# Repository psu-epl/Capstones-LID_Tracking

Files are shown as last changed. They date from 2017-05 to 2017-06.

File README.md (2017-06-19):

Capstones-LID_Tracking
------

###### This is the top level directory for the Capstone Awesome Usage Monitor project. The following repo directories contain the files used by this project and the developers to specify, design, and implement the project. This directory may be copied whole into any preconfigured Django AUM project instance. See below on how to configure and setup an AUM project instance.

---

* ./sm/ - Files associated with the Station Module. Not used by Django.
* ./aum/ - Django associated python files for the aum project and used by all applications.
* ./aumwi/ - Django associated python files for the web interface application.
* ./doc/ - Project Documentation, including User Manuals.
* ./static/ - css, js, img, and font files used by Django to render webpages, organized by project
* ./templates/registration/ - Django authentication and password management html files
* ./testing/ - Testing software and associated coverage results zip
* ./manage.py - Django management code.

---

The development environment for the Awesome Usage Monitor used an Ubuntu 16.04 server instance with python3.0 installed and running as a virtual environment.  The server was configured with SMTP, a postgreSQL database, Gunicorn application server, and Nginx setup as the webserver and the reverse proxy to Gunicorn.  Django 1.11 was used to develop the project.

---

The test environment was created using pytest and pytest-django for python3, for detailed instructions on how to create additional tests or verify the functionality of your production instance of the Awesome Usage Monitor please visit this [Pytest-Django Tutorial](http://pytest-django.readthedocs.io/en/latest/tutorial.html)

---

For detailed instructions on how to create a production environment similar to the development environment please visit this [DigitalOcean Tutorial](https://www.digitalocean.com/community/tutorials/how-to-set-up-django-with-postgres-nginx-and-gunicorn-on-ubuntu-16-04).

---

For detailed documentation on any Django function used within the project, please refer to the [Django 1.11 Documentation](https://docs.djangoproject.com/en/1.11/) or the [Django source code](https://github.com/django/django), both of which are extensive and extremely helpful.

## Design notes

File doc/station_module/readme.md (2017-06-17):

## Station Module

[How to set up the module](Setup.md) (connect to the Wifi, set parameters, etc)

[Using the Module](use.md)

[Brief description of Hardware and pin assignments](pin.md)

[Bill of Materials](bom.md)

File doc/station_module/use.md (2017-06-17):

### Using the Station Module:

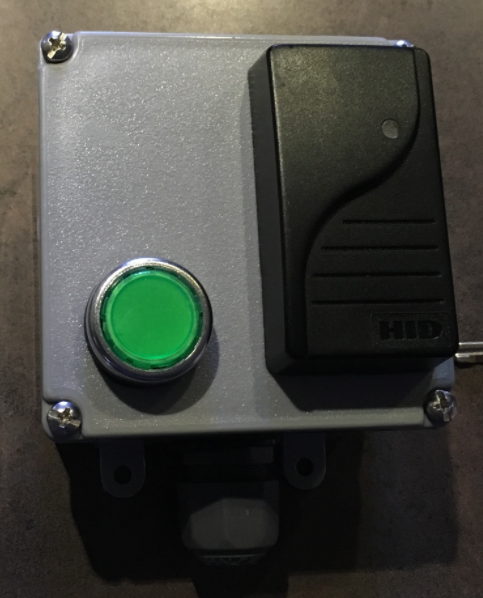
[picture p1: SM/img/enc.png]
Station Module in Enclosure


#### Normal Login
When a registered user swipes a card, the SM sends a request to the database, if the user is authorized, the SM light a green LED and send power to the external relay. The database logs the entry with a timestamp. It can take up to 4 seconds to recieve a reply from the server.
If the user is unauthorized, the SM will emit a beep and remain off.
If it takes 15s or more to get a reply, this indicates that the SM is timing out with the server. Debugging info is available on the serial port of the SM.

#### Logout
Pushing the attached button causes the relay to be shut off and a logout command to be sent to the database. A logout timestamp is added to the last login entry.

#### Double Scanning
If a user is logged in, and another user badges in on top of them, the module will stay logged in under the new user.
If an unauthorized user tries to login over an existing session, the SM will end the session.

#### Add user
For a manager to add a user, they will hold down the button and scan their badge. The SM will blink alternating red and green for 10 seconds. The new user will scan their badge and the info is sent to the database.  If the add is successful, the SM will log in.

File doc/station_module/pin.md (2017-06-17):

#### ESP8266 - 12E 
<a href="https://espressif.com/en/products/hardware/esp8266ex/overview">EXPRESSIF</a>

This module was chosen for it's cost/size/power consumption, and prior experience the team had using them.<br>
Also the following:
- Features:
  - 802.11 b/g/n
  - Integrated TCP/IP protocol stack
  - 32-bit MCU running at 80MHz
  - 4M Flash memory
  - Integrated 10-bit ADC
  - SDIO 2.0, (H) SPI, UART, I2C, I2S, IRDA, PWM, GPIO

#### ESP Pin Functions:
| Pin | Function |
|---|---|
| GPIO 0  | Green LED status indicator |
| GPIO 1  | SPI Slave Select 1 |
| GPIO2 | Audible alarm control |
| GPIO 3  | SPI Slave Select 2 |
| GPIO 4  | RFID-DATA1 |
|  GPIO 5 | RFID-DATA0 |
| GPIO 12 | SPI MOSI |
| GPIO 13 | SPI MISO |
| GPIO 14 | SPI Clock |
| GPIO 15 | APD Enable |
| ADC | Stop / Logout |

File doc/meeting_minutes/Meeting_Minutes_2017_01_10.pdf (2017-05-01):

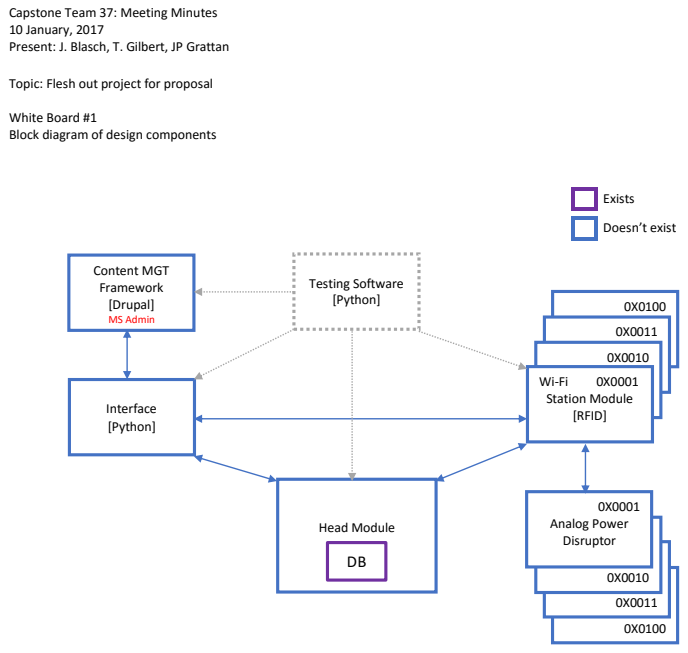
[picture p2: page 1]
Content MGT Framework [Drupal] MS Admin; Interface [Python]; Head Module; Station Module [RFID]; Testing Software [Python]; 0X0001 Analog Power Disruptor; Exists; Doesn’t exist

Capstone Team 37: Meeting Minutes
10 January, 2017
Present: J. Blasch, T. Gilbert, JP Grattan

Topic: Flesh out project for proposal

White Board #1
Block diagram of design components

0X0011
0X0010

10 January, 2017
Present: J. Blasch, T. Gilbert, JP Grattan

Whiteboard #2
Block diagram of interface setup

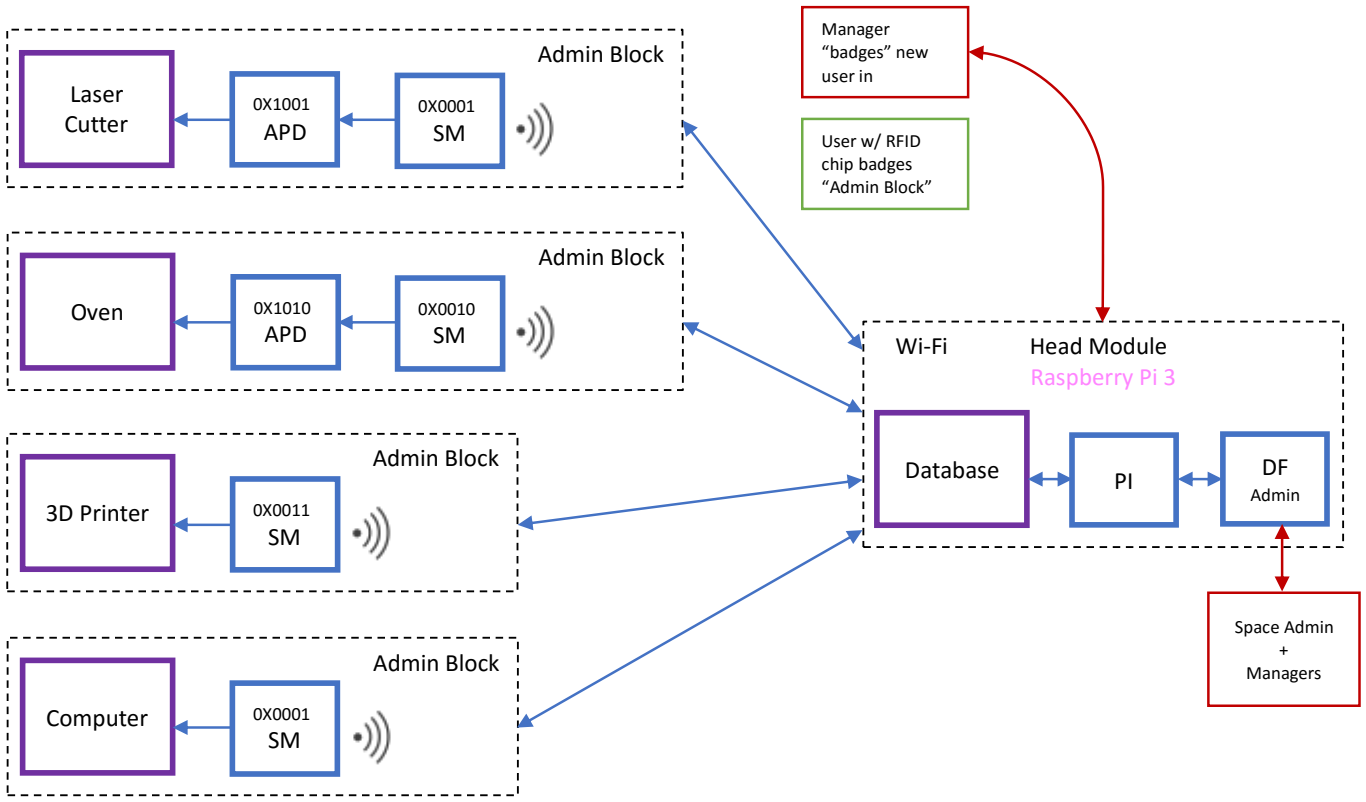
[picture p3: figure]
Admin Block; Laser Cutter; 0X1001 APD; Oven; APD; 3D Printer; Computer; Head Module; Raspberry Pi 3; Database; Admin PI; Space Admin + Managers; Manager “badges” new user in; User w/ RFID chip badges “Admin Block”

10 January, 2017
Present: J. Blasch, T. Gilbert, JP Grattan

Whiteboard #3
Design Questions

SM = Station Module

How does a new user get added to the “list”?

- Manager badges twice within 1 second and within x-seconds the user badges. | Individual
- Manager badges and, while the manager pushes a button, the user badges. | – MIX
- Manager accesses Drupal frontend and manually adds user. | Batch & individual

What does a “pass” event look like?

User puts RFID card to SM. SM communicates wirelessly with database and receives “pass”. SM sends signal to APD to turn on and credentials to log in to computer.

What does a “fail” event look like?

User puts RFID card to SM. SM communicates wirelessly with database and receives “fail”. SM alerts with audio and visual signal.

How does the SM pass credentials?

This is uncertain and subject to further investigation. It is physically attached to the computer, so perhaps USB.

How does the SM communicate with the APD?

This is uncertain and subject to further investigation. It is physically attached to the APD, so perhaps I²C.

Perhaps audio and visual “pass” signal for manager?

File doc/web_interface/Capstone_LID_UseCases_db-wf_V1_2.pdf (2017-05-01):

### CAPSTONE – LID: Use Cases db/web framework

Version 1.2

Team: Jessica Blasch, Tyson Gieszler, Tyler Gilbert, JP Grattan

Version History
Version # | Revision Date | Responsible Party | Reason
1.0 | 27 February, 2017 | Jessica Blasch | Initial compilation of source document
1.1 | 04 March, 2017 | Jessica Blasch | Revision to create simpler use cases
1.2 | 015 March, 2017 | Jessica Blasch | Revision add use cases for reports ‘Prev’/’Next’ BTN

## Table of Contents

## Access the System: Logging In

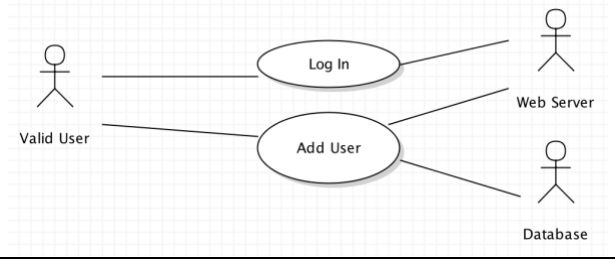
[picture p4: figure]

Use Case | Log in
Actors | Valid user, Web server, Database
Description | This use-case occurs when a valid user (owner, admin, or manager) logs in to the system. The web server will prompt the user for their log-in information. If they are not a valid user, the system will not allow them access past the log-in page. If they are a valid user, they will be directed to the ‘Add User’ page view. The ability to make a new user an owner, admin, or manager will be made available depending on the user’s status. (e.g. If owner, display options for make owner, admin, or manager. If admin only display ‘make manager’ . If manager, do not display options to make owner, admin, or manager.)
Stimulus | User logs in to system.
Response | Verify user is a valid user and their status. If valid, trigger appropriate ‘Add User’ page view with respect to the user’s credentials

## Exit the System: Logging Out

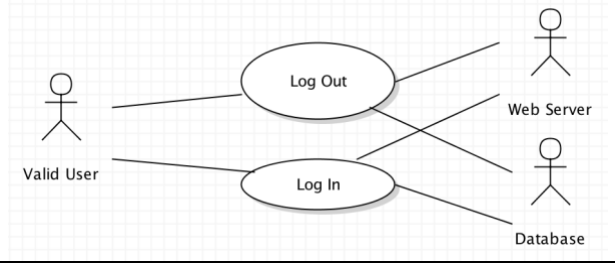
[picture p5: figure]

Use Case | Log Out
Actors | Valid user, Web server, Database
Description | This use-case occurs when a valid user (owner, admin, or manager) is in the system and wants to log out. When the user selects the ‘Log Out’ button, the web server will redirect to the ‘Log In’ page view.
Stimulus | User selects ‘Log Out’ button.
Response | Trigger ‘Log In’ page view.

## Add a New User

### Navigating to the ‘Add User’ Page

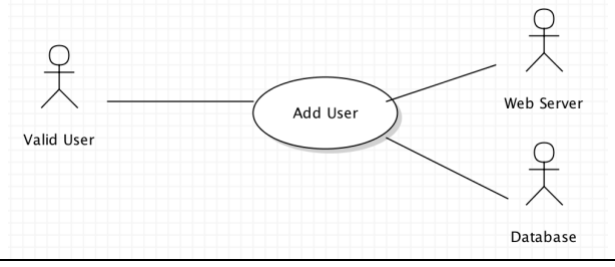
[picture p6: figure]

Use Case | Display ‘Add User’ Page View
Actors | Valid user, Web server, Database
Description | This use-case occurs when a valid user (manager, admin, or owner) must navigate to the ‘Add User’ page view from another page view by selecting the ‘Add User’ button. Upon selecting the ‘Add User’ button, the web server will redirect to the ‘Add User’ page view.
Stimulus | User selects ‘Add User’ button.
Response | Trigger ‘Add User’ page view.

### Saving a New User Entry

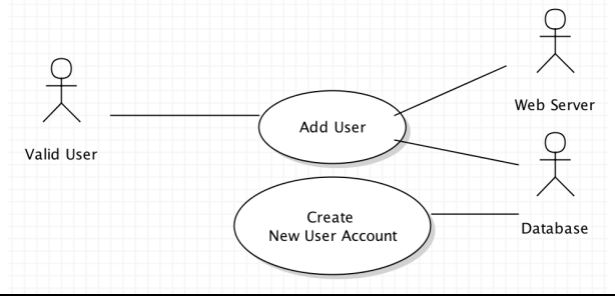
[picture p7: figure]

Use Case | Save New User Entry
Actors | Valid user, Web server, Database
Description | This use-case occurs when a valid user (manager, admin, or owner) is at the ‘Add User’ page view. The user may then fill in information in editable fields for a new user account and save it as a new entry in the database.
Stimulus | User selects ‘Save’ button.
Response | Verify all fields are correctly filled out. Save as new user account entry in database.

## Search for a User

### Navigating to the ‘Find User’ Page

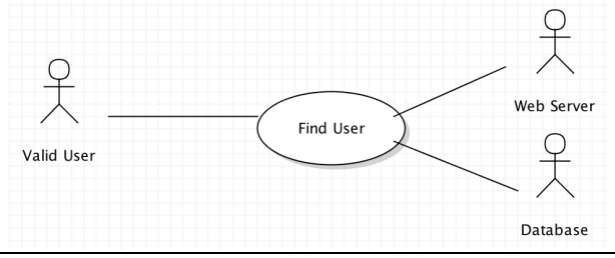
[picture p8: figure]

Use Case | Display ‘Find User’ Page
Actors | Valid user, Web server, Database
Description | This use-case occurs when a valid user (manager, admin, or owner) navigates to the ‘Find User’ page view by selecting the ‘Find User’ button.
Stimulus | User selects ‘Find User’ button.
Response | Trigger ‘Find User’ page view.

Searching for a User with Name –AND– I.D.

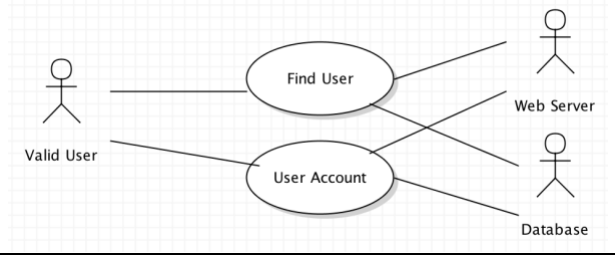
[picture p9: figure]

Use Case | Search User Account with Name –AND– I.D.
Actors | Valid user, Web server, Database
Description | This use-case occurs when a valid user (manager, admin, or owner) is at the ‘Find User’ page view. If the user enters the name and badge I.D. that matches an entry in the database, when they select the ‘search’ button, they will be directed to the specific account page for that user.
Stimulus | User selects ‘Search’ button.
Response | Verify all fields match a database entry. If valid, trigger ‘User Account’ page view.

Searching for a User with Name –OR– I.D.

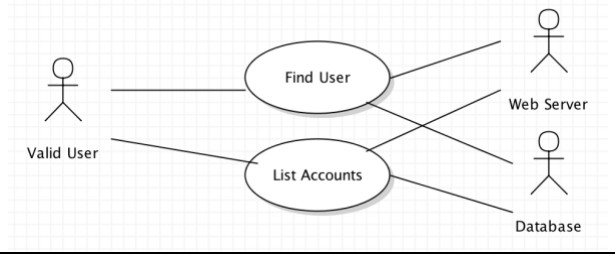
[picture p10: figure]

Use Case | Search User Account with Name –OR– I.D.
Actors | Valid user, Web server, Database
Description | This use-case occurs when a valid user (manager, admin, or owner) is at the ‘Find User’ page view. If the user does not enter all fields (name and badge I.D.) or does not enter a name and badge I.D. that matches an entry in the database, when they select the ‘search’ button, they will be directed to a list of users and badge I.D.s with fields that match any of the fields searched for. The user may then write down the information they need and search again using the ‘Find User’ button.
Stimulus | User selects ‘Search’ button.
Response | Verify all fields match a database entry. If not valid, trigger ‘List Accounts’ page view of user accounts with fields that match search criteria.

## Edit a User Account

### Navigating to an Editable User Account

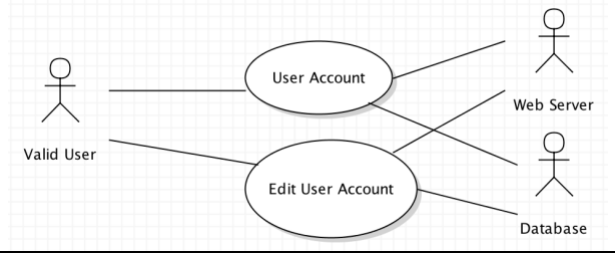
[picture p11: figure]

Use Case | View Editable User Account
Actors | Valid user, Web server, Database
Description | This use-case occurs when a valid user (manager, admin, or owner) is at a specific ‘User Account’ page view. If the user selects the ‘Edit’ button, they will be redirected to an ‘Edit User Account’ page view with editable fields for the user searched.
Stimulus | User selects ‘Edit’ button.
Response | Trigger ‘Edit User Account’ page view.

### Saving User Account Edits

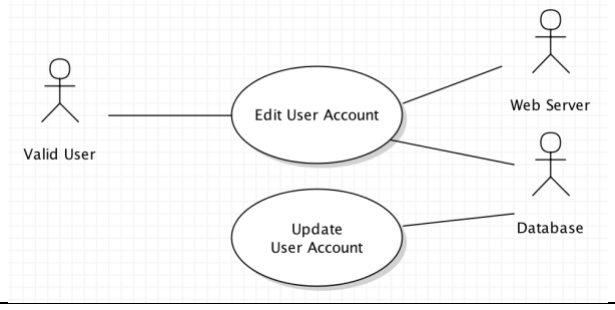
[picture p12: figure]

Use Case | Save User Account Edits
Actors | Valid user, Web server, Database
Description | This use-case occurs when a valid user (manager, admin, or owner) is at the ‘Edit User Account’ page view. From this page, the user can edit fields of a user account including status as an owner, admin or manager if they have appropriate credentials. (e.g. If owner, display options for make owner, admin, or manager. If admin only display ‘make manager’ . If manager, do not display options to make owner, admin, or manager.)
Stimulus | User selects ‘Save’ button.
Response | Verify all fields are correctly filled out. Save edits for account entry in database.

## Delete a User Account

### Navigating to Delete User Account

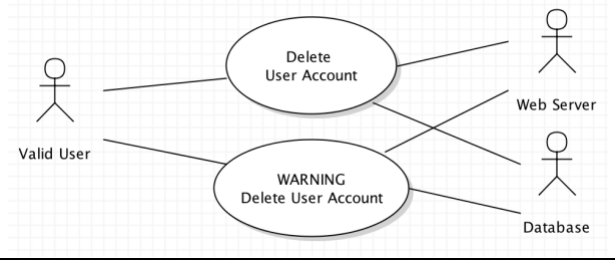
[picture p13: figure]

Use Case | Begin Delete User Account
Actors | Valid user, Web server, Database
Description | This use-case occurs when a valid user (manager, admin, or owner) is at a specific ‘User Account’ page view. If the user selects the ‘Delete’ button, they will be redirected to a ‘Warning’ page view to confirm or cancel deletion.
Stimulus | User selects ‘Delete’ button.
Response | Trigger ‘Warning’ page view.

### Canceling User Account Deletion

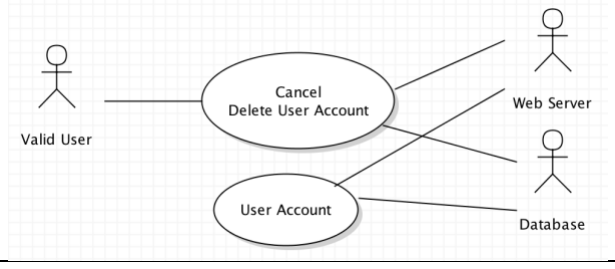
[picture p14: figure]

Use Case | Cancel Delete User Account
Actors | Valid user, Web server, Database
Description | This use-case occurs when a valid user (manager, admin, or owner) is at the ‘Warning’ page view, before account deletion. If the user selects the ‘Cancel’ button, they will be redirected back to the specific ‘User Account’ page view.
Stimulus | User selects ‘Cancel’ button.
Response | Trigger ‘User Account’ page view.

### Confirming User Account Deletion

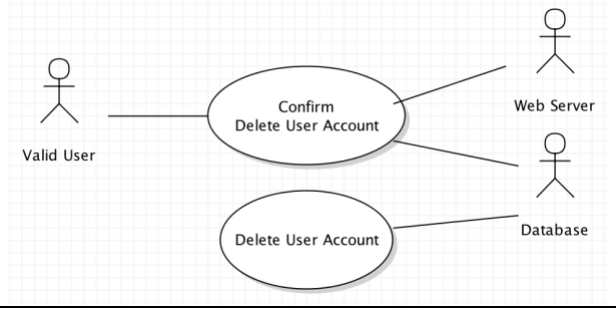
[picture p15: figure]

Use Case | Confirm Delete User Account
Actors | Valid user, Web server, Database
Description | This use-case occurs when a valid user (manager, admin, or owner) is at the ‘Warning’ page view, before account deletion. If the user selects the ‘Confirm’ button, the entry will be removed from the database and the user will be redirected to a ‘Delete Confirmation’ page view which will confirm the deletion has occurred.
Stimulus | User selects ‘Confirm’ button.
Response | Delete user account entry in the database. Trigger ‘Delete Confirmation’ page view.

## Search for a Station

### Navigating to the ‘Find Station’ Page

Use Case | Display ‘Find Station’ Page
Actors | Valid user, Web server, Database
Description | This use-case occurs when a valid user (manager, admin, or owner) navigates to the ‘Find Station’ page view by selecting the ‘Find Station’ button.
Stimulus | User selects ‘Find Station’ button.
Response | Trigger ‘Find Station’ page view.

### Searching for a Station

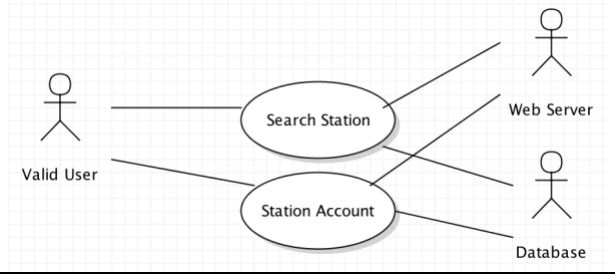
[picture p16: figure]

Use Case | Search for a Station
Actors | Valid user, Web server, Database
Description | This use-case occurs when a valid user (manager, admin, or owner) is at the ‘Find Station’ page view. At this page view, the user can enter in the I.D. of the station they wish to look up. After selecting the ‘search’ button, the web server will verify the I.D. matches an entry in the database and redirect the user to a page view of the station’s information.
Stimulus | User selects ‘Search’ button.
Response | Verify I.D. matches a database entry. Trigger ‘Station Account’ view.

## Edit a Station

### Navigating to an Editable Station View

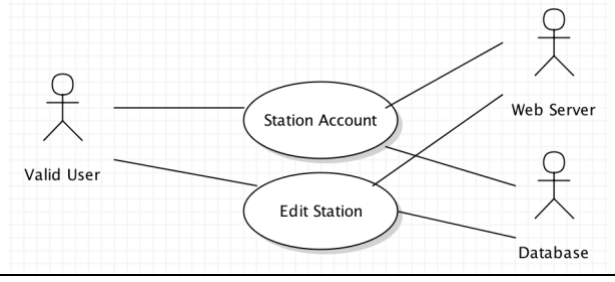
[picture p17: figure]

Use Case | Go to Editable Station View
Actors | Valid user, Web server, Database
Description | This use-case occurs when a valid user (manager, admin, or owner) is at a station account page view. After selecting the ‘edit’ button, the web server will redirect them to an editable page view of the station’s information.
Stimulus | User selects ‘Edit’ button.
Response | Trigger ‘Edit Station’ page view.

### Saving Station Edits

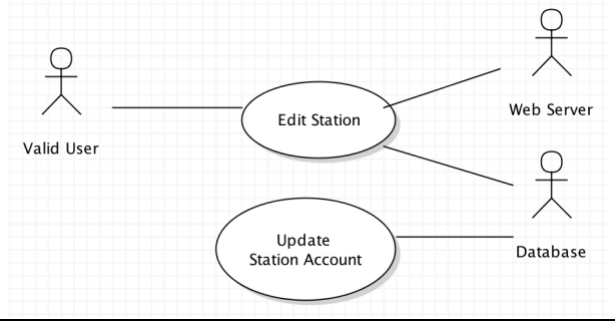
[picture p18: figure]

Use Case | Save Station Edits
Actors | Valid user, Web server, Database
Description | This use-case occurs when a valid user (manager, admin, or owner) is at the editable station account page view. After selecting the ‘save’ button, the information will be updated and stored in the database.
Stimulus | User selects ‘Save’ button.
Response | Update station account in database.

## Delete a Station

### Removing a Station

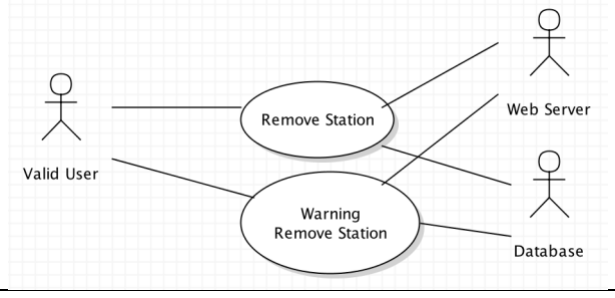
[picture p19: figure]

Use Case | Remove a Station
Actors | Valid user, Web server, Database
Description | This use-case occurs when a valid user (manager, admin, or owner) is at a station account page view. If the user selects the ‘Remove Station’ button, they will be redirected to a ‘Warning’ page view where they can cancel or confirm the data entry deletion.
Stimulus | User selects ‘Remove Station’ button.
Response | Trigger ‘Warning’ page view.

### Cancelling Station Deletion

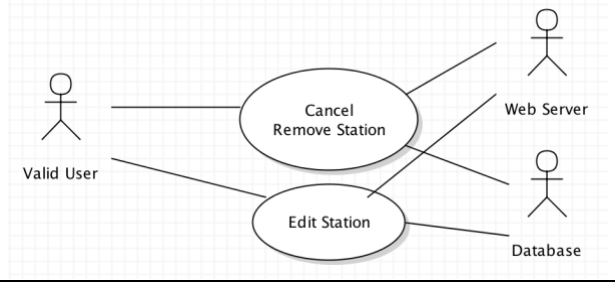
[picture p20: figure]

Use Case | Cancel Station Removal
Actors | Valid user, Web server, Database
Description | This use-case occurs when a valid user (manager, admin, or owner) is at the ‘Warning’ page view for station removal. If the user selects the ‘Cancel’ button, they will be redirected to a ‘Editable Account’ page view as though they had selected ‘Edit’ from the station account page view. From there, the user may select save and continue.
Stimulus | User selects ‘Cancel’ button.
Response | Trigger ‘Edit Station’ page view.

### Confirming Station Deletion

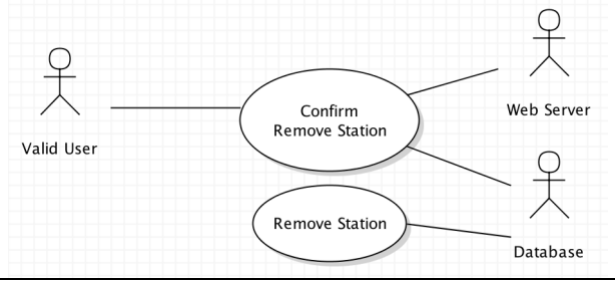
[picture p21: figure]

Use Case | Confirm Station Removal
Actors | Valid user, Web server, Database
Description | This use-case occurs when a valid user (manager, admin, or owner) is at the ‘Warning’ page view. If the user selects the ‘Confirm’ button, the station entry will be deleted from the database and the user will be redirected to a page view showing the station has been removed.
Stimulus | User selects ‘Confirm’ button.
Response | Delete station account entry in the database.

## Reports

### Running a General Report

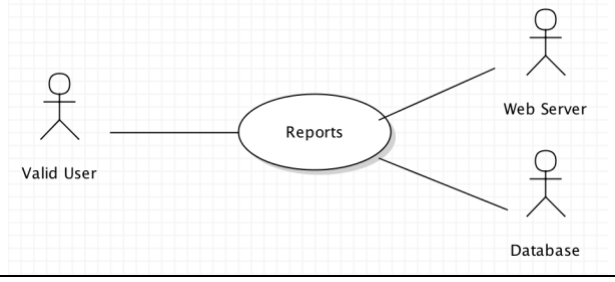
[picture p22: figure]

Use Case | Run a General Report
Actors | Valid user, Web server, Database
Description | This use-case occurs when a valid user (manager, admin, or owner) selects the ‘Reports’ button from the side table. The web server will redirect to a general ‘Report’ page view that displays all tracked data.
Stimulus | User selects ‘Reports’ button.
Response | Trigger ‘Report’ page view.

### Running a Filtered Report

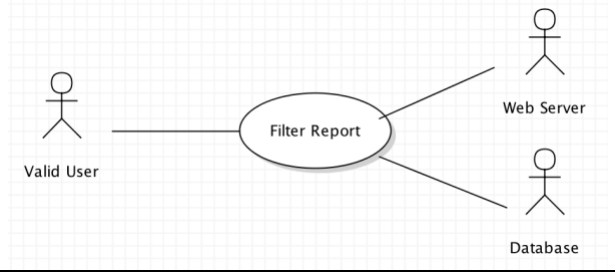
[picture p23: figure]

Use Case | Run a Filtered Report
Actors | Valid user, Web server, Database
Description | This use-case occurs when a valid user (manager, admin, or owner) is at the general ‘Report’ page view that displays all tracked data. The user may select filter options to pare down the data displayed
Stimulus | User selects ‘Filter’ button.
Response | Verify filter selections and match to database entries. Trigger ‘Filter Report’ page view.

### Navigating Reports by Page Number

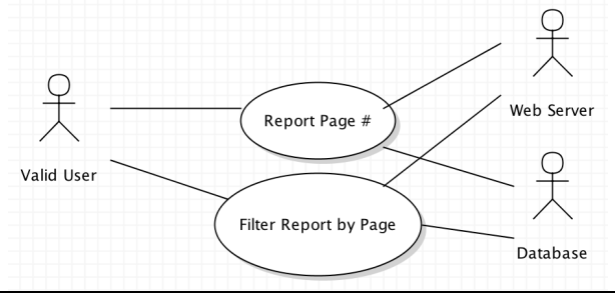
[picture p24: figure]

Use Case | Navigate Report by Page Number
Actors | Valid user, Web server, Database
Description | This use-case occurs when a valid user (manager, admin, or owner) is at the either the general ‘Report’ page view or “Filter Report’ page view. If the user selects one of the buttons for the pages of data in the report, the webserver will redirect to the page view for that part of the report data.
Stimulus | User selects ‘page number’ button.
Response | Verify the number selected. Trigger page view for that section of the report data.

### Navigating Reports with ‘Next’


Use Case | Navigate Report Pages
Actors | Valid user, Web server, Database
Description | This use-case occurs when a valid user (manager, admin, or owner) is at the either the general ‘Report’ page view or “Filter Report’ page view. If the user selects the ‘Next’ button for the pages of data in the report, the webserver will redirect to the page view for the next section of the report data.
Stimulus | User selects ‘Next’ button.
Response | Verify there is further data to display. Trigger ‘Next Page’ view.

### Navigating Reports with ‘Prev’


Use Case | Navigate Report Pages
Actors | Valid user, Web server, Database
Description | This use-case occurs when a valid user (manager, admin, or owner) is at the either the general ‘Report’ page view or “Filter Report’ page view. If the user selects the ‘Prev’ button for the pages of data in the report, the webserver will redirect to the page view for the previous section of the report data.
Stimulus | User selects ‘Prev’ button.
Response | Verify not displaying first page of data. Trigger ‘Previous Page’ view.

### Export Report as CSV File


Use Case | Export Report as CSV file
Actors | Valid user, Web server, Database
Description | This use-case occurs when a valid user (manager, admin, or owner) is at the either the general ‘Report’ page view or “Filter Report’ page view. If the user selects the ‘Export as CSV’ button, the data being displayed will be exported as a CSV file.
Stimulus | User selects ‘Export as CSV’ button.
Response | Export data as CSV file.

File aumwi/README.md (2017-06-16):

Awesome Usage Monitor Web Interface
------

* ./templates/ - Application specific html templates
* ./__init__.py - Python file to designate the directory as an importable package. May be empty or contain package initialization instructions.
* ./admin.py - Application override functions for Django model administration
* ./apps.py - Application configuration class definitions and settings
* ./forms.py - Model form definitions
* ./managers.py - Application override classes for model "managers". Django managers perform admin functions on the database models. 
* ./models.py - Application definitions for database models.
* ./test.py - Application specific testing definitions. None currently. 
* ./urls.py - Appliation specific url patterns for resolving http requests. Associates a url pattern with a function to be run by the application.
* ./views.py - Application specific class and function definitions. A "view" defines the backend rendering and processing logic for a url

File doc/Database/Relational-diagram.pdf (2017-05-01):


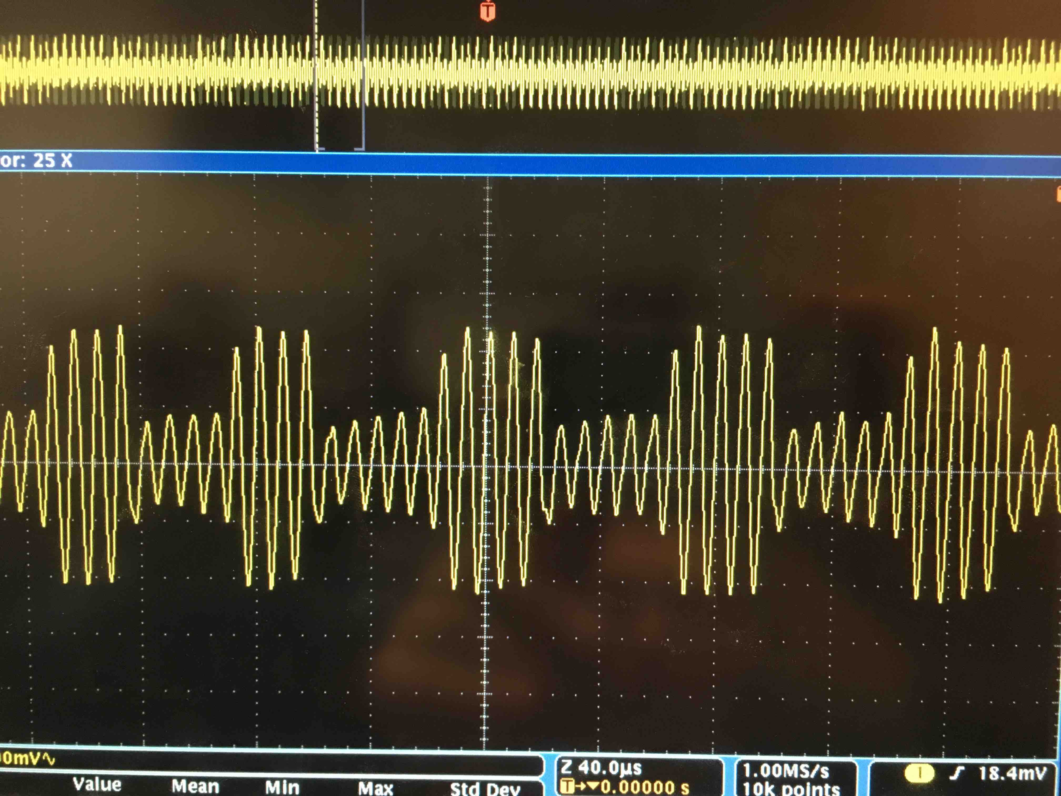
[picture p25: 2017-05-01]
doc/station_module/PSUID.jpg

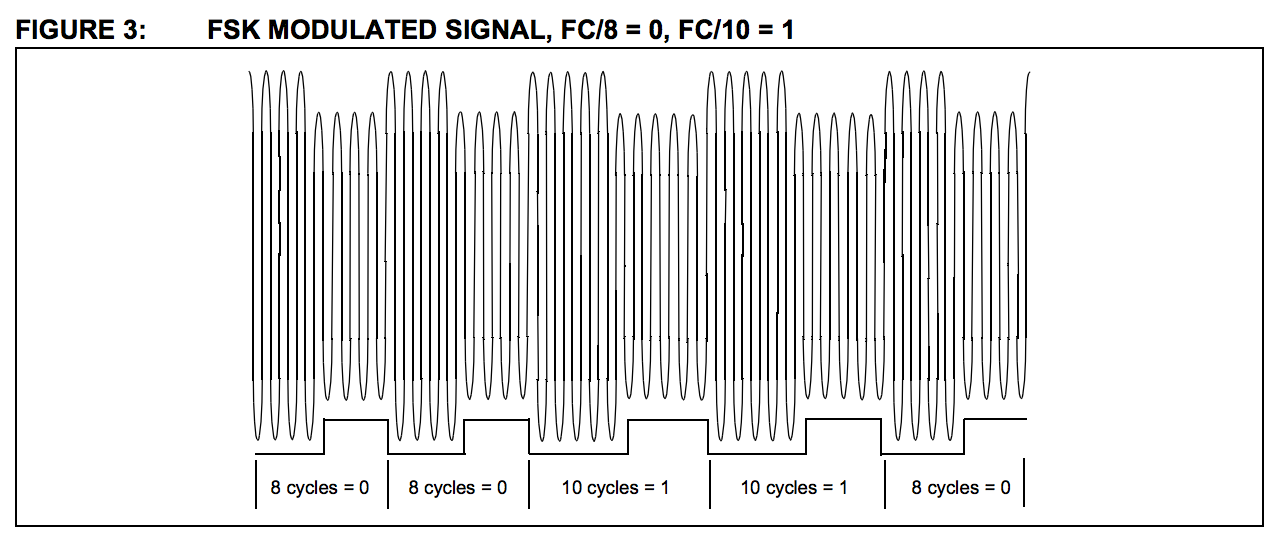
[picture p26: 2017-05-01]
doc/station_module/FSK_modulation.png

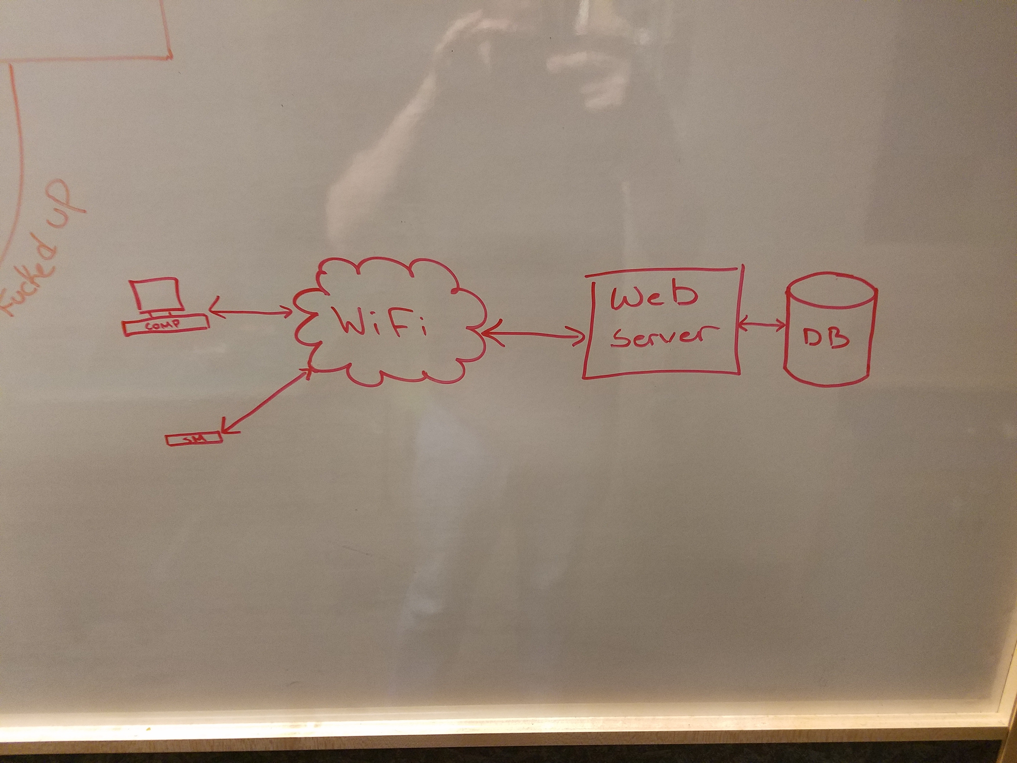
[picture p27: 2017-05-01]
doc/web_interface/Comm_Channels_prelim.jpg

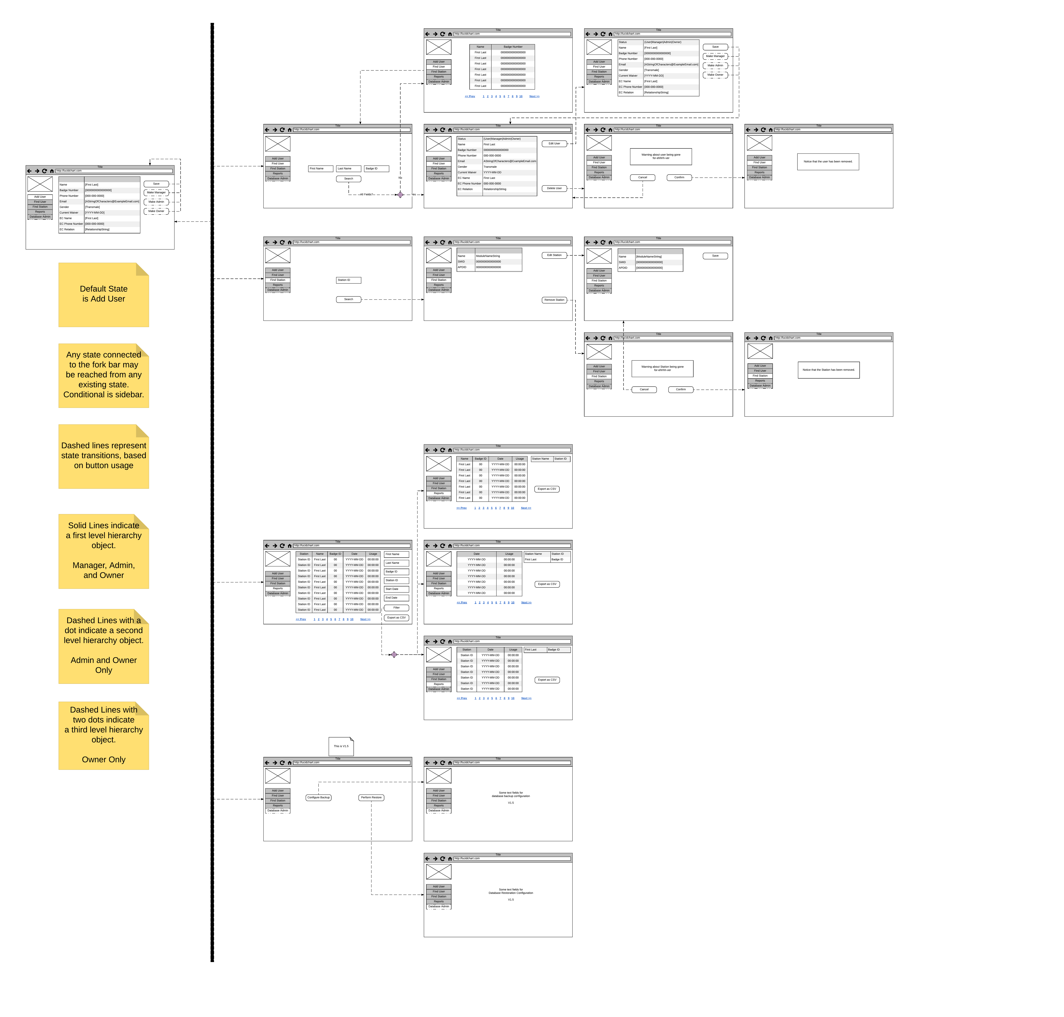
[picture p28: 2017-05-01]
doc/web_interface/Site_State_Diagram.png

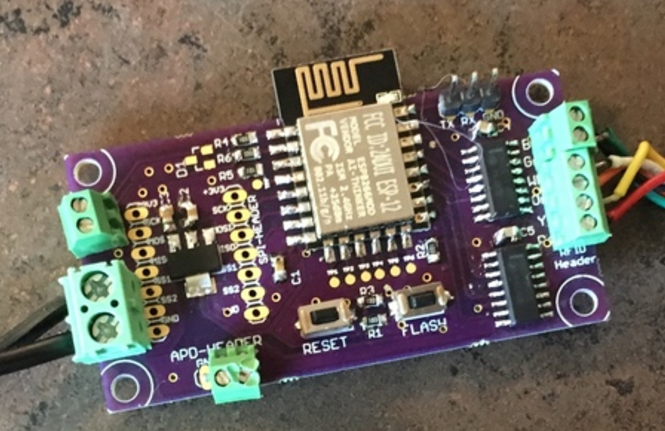
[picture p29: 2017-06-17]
doc/station_module/img/HW.png

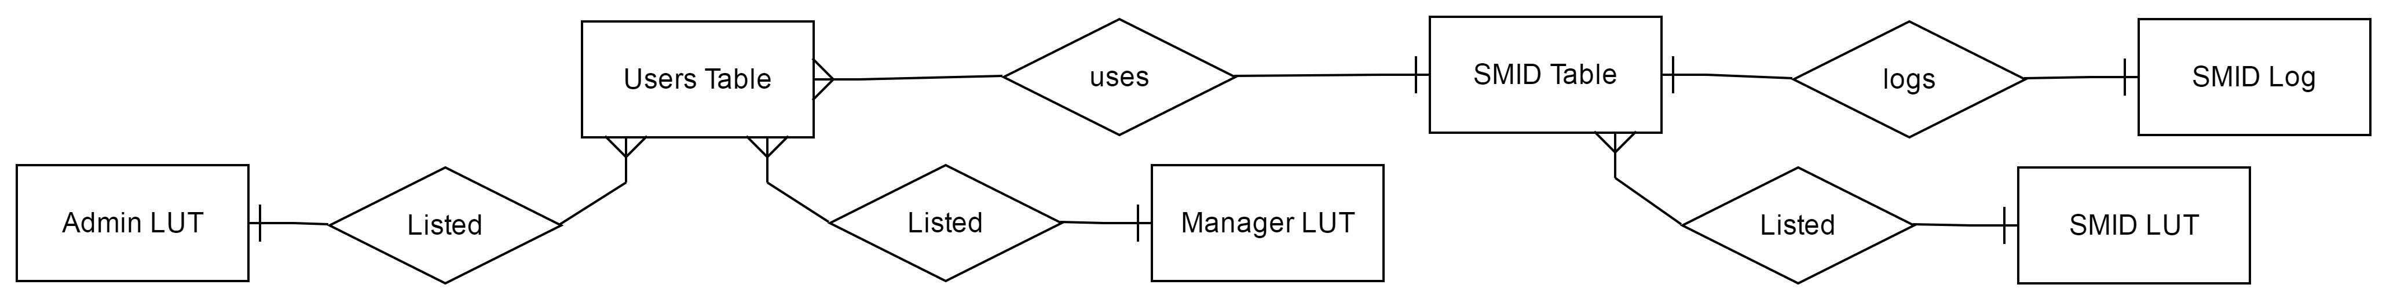
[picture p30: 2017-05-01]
doc/Database/Entity-diagram.png

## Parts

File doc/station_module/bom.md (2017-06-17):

### BOM:

The relay control output will supply a 5V signal at up to 6mA.
[Power Switch Tail 2](http://www.powerswitchtail.com/) was used successfully. It is superceded by the [IOT Relay](http://www.digital-loggers.com/iot.html), which can be found at [Adafruit](https://www.adafruit.com/product/2935)

The RFID readers that will work with this module are the [HID-PROX 125kHz readers](https://www.hidglobal.com/products/readers/hid-prox-readers)
 (HID Proxpro II, HID Proxpoint plus.. etc) that use the Wiegand protocol.

| Qty | Value | Device | Package | Parts | Description | Digikey | Mouser |
|-----|---|---|---|---|---|---|---|
| 1 | | ESP12ESMD  | ESP12E-SMD | U1 | ESP12E Module | 1528-1438-ND | 485-2491 |
| 1 | 3.3V  | D1 | SOT23 | D1 | TVS Diode | MMBZ5V6ALT1GOSCT-ND | 863-MMBZ5V6ALT1G |
| 2 | | DTSM-3 | DTSM-3 | S1,S2 | flash and reset button | 450-2146-1-ND | FSM2JMTR |
| 1 | 3.3V  | REG1117 | SOT223 | IC1 | 800mA and 1A Low Dropout (LDO) Positive Regulator  | AZ1117CH-3.3TRG1DICT-ND | 621-AZ1117CH-3.3TRG1 |
| 2 | | 4050B | 16-SOIC | U1, U2 | 6ch Buffer | MC14050BDR2GOSCT-ND | 863-MC14050BDR2G |
| 2 | 1x7 | | FEM 1x7POS .1" | SPI_Header | SPI header breakout(optional) | | |
| 1 | 1x6 | | Term block 6-pos .1" screw term | APD / RFID Header  | Screw Terminal for RFID scanner | ED10565-ND | |
| 1 | 1x4 | | Term block 4-pos .1" | | Screw terminal for Power (Optional) | ED10563-ND | 651-1725672 |
| 1 | 1x2 | | Term block 2-pos .1" | | Screw terminal for stop button (Optional) | ED10561-ND | 571-282834-2 |
| 3 | 100n  | C0805K | 0805 | C1, C4, C5 | bypass cap | | |
| 2 | 10u | C0805K | 0805 | C3,C3 | 3.3v reg input cap | | |
| 5 | 10k | R-US_R0805 | 0805 | R1, R2, R3, R4, R5 | RESISTOR | | |
| 1 | 33k | R-US_R0805 | 0805 | R6 | RESISTOR | | |

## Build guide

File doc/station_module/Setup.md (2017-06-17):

### How to connect the module to the Wifi
The Station Module will automatically try to connect to the last known good Wifi. If it cannot connect, it will restart itself and set up an Access Point called **AUM_Station_Module**. 
The AP has a captive portal, so anytime you connect, you will be redirected to the config page. This mode can also be accessed at any time by holding down the “logout” button for a few seconds while cycling power or doing a reset.
 
**Captive Portal Page:**
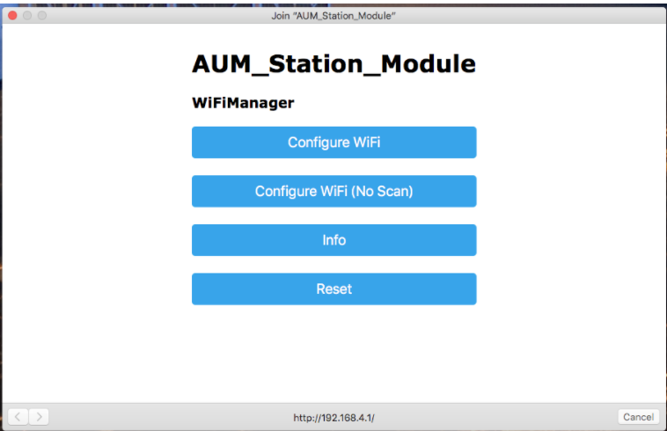
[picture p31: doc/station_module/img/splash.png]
Captive Portal

- select “Configure WiFi”

**Configuration Page:**
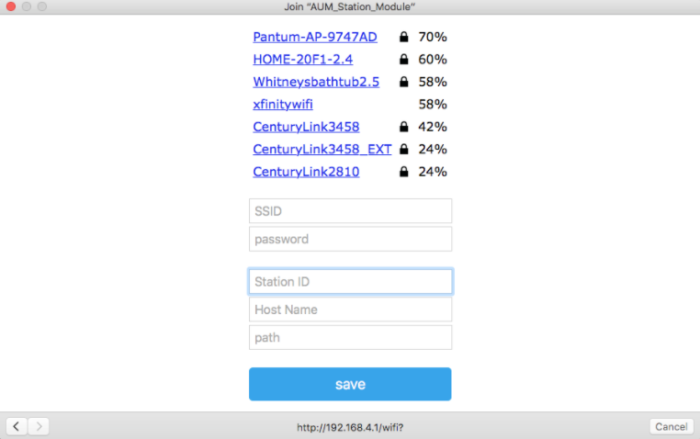
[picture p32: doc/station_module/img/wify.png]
Config

- Click the AP you want to connect to.
- Fill in password
- Fill in station module ID
- Fill in host name. Ex:  aummanage.com
- Fill in path. Ex:   \aum
- click save and the unit will restart
 
---
The Wifi and password credentials will persist after a hard reset, however, the function to save the host and custom path in EEPROM was not implemented due to complications getting it to work.  They will revert to the default values if power is cycled.
---
 
**Important:** For the host and path: Don't use http:// for the host, just "host.com" or whatever.  For the path, the first character should be a slash, with no trailing slash.

If the network you are trying to connect to requires a username and a password, then you must contact the network administrator and register the station module’s MAC address. Usernames and passwords are not supported on this device.
You will need the MAC address:  
In the captive portal, Click on info:  the Station MAC is listed.

**Info Page** 
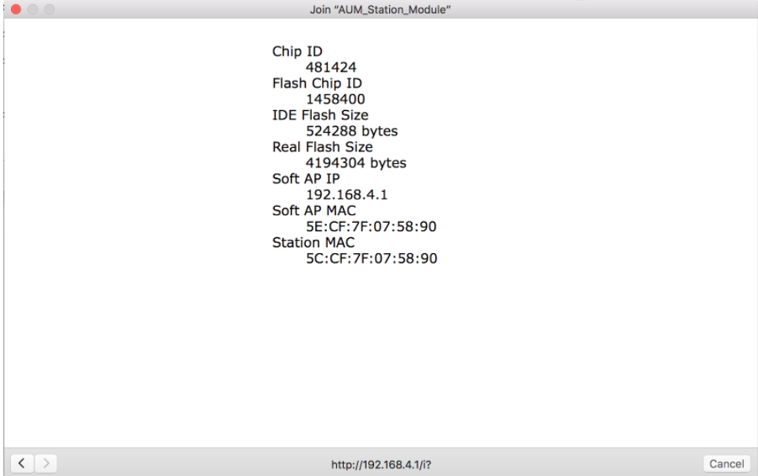
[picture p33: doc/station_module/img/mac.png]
info page


  **For PSU:**   Browse to:    [https://intranet.pdx.edu/oit/internet-device-registration](https://intranet.pdx.edu/oit/internet-device-registration)  and fill out a  Internet Device Registration request.

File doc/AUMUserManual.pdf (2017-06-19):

AUM User Manual
Rev 0.2
June 19 2017

# Table of Contents

Chapter 1: The Awesome Usage Monitor | 4
1.1 Introduction | 4
1.2 Requirements | 4
1.3 Station Module | 4
1.4 PowerSwitch Tail 2 | 5
1.5 User Interface | 5
1.6 The Git Repository | 5
Chapter 2: The Web Framework and Database | 6
2.1 The Development Environment | 6
2.2 The Production Environment | 6
Chapter 3: The Station Module | 7
3.1 How to connect the module to the Wifi | 7
3.2 How to connect the module to the tool | 9
3.3 How to link the module to the database | 9
3.4 How to add a user to the Authorized User list for a tool | 9
3.5 How a user logs into the tool | 10
3.6 How a user logs out of the tool | 10
Chapter 4: The User Interface | 11
4.1 Site Navigation | 11
4.2 Users | 12
4.2.1 Adding a user | 13
4.2.2 Editing a user | 14
4.2.3 Deleting a user | 15
4.2.4 Adding a user to the Authorized User list | 16
4.2.5 Searching for a User | 17
4.3 Station Modules | 18
4.3.1 Adding a Station Module | 18
4.3.2 Editing a Station Module | 19
4.3.3 Deleting a Station Module | 20
4.3.4 Searching for a Station Module | 21
4.4 Authorized User Lists | 22
4.4.1 Adding a user to an Authorized User list | 22
4.4.2 Removing a user from an Authorized User list | 23
4.5 Reports | 24
4.5.1 Running a report | 24

4.5.2 Exporting a report | 25
4.5.3 Report Examples | 26
Use By Station Module | 26
Use by User | 27
Use by Date | 28
Use by User and Station Module | 29
Use by Station Module and Date | 30
Use by User and Date | 31
Use by User, Station Module, and Date | 32
4.6 Database Administration | 33
4.6.1 Backup Database | 33
4.6.2 Restore Database | 34

# Chapter 1: The Awesome Usage Monitor

## 1.1 Introduction

The Awesome Usage Monitor (AUM) has two main purposes: to track the usage of the tools within the labs workspace, and to restrict access to a specific tool if the user is not trained in its proper use.

There are three main components to the Awesome Usage Monitor.
1. The Station Modules
2. The PowerSwitch Tail 2
3. The User Interface
For setting up any of these devices please refer to their respective section.

## 1.2 Requirements

In order to begin using the AUM, it is important that you have the following production environment properly installed, updated, and configured for your specific network and security requirements. The AUM repository consists only of the Project files, and does not contain any files from any third party repositories. It is assumed that you have a fresh installation of Ubuntu Server, or equivalent, as well as the following third party applications installed on your production server.

1. Ubuntu Server with:
a. OpenSSH
b. Postfix
c. PostgreSQL
d. git
e. Python3.x
f. Gunicorn
g. Nginx
h. Django 1.1
2. An internally or externally hosted domain

## 1.3 Station Module

The Station Module is an RFID based device used for controlling access and logging usage of your tools within the lab. Users will tap their RFID enabled card or FOB to the Station Module’s card reader when they intend to activate the tool. The Station Module then checks the RFID based credentials of the user with respect to the tool it is attached to. If the user is authorized, the Station Module triggers the PowerSwitch Tail 2 to switch power to the tool. Otherwise, the tool remains unable to be powered on.

## 1.4 PowerSwitch Tail 2

This is an off the shelf solution for controlling power to a tool. When a “go” signal is sent to the PowerSwitch Tail 2 (PST2), it allows power from the wall to the tool. Otherwise, the power is off.

## 1.5 User Interface

The User Interface is the web based administration website used to create, modify, and query the underlying database. Through the User Interface you can:

1. Add, Modify, View, and Delete a User
2. Add, Modify, View, and Delete a Tool
3. Add, Modify, View, and Delete a Station Module
4. Modify and View TimeStamps for Station Module usage
5. Run, Manage, and Export administrative reports.

## 1.6 The Git Repository

The AUM repository is held on Github, (https://github.com/psu-epl/Capstones-LID_Tracking) and may require permissions to access the repo. Contact: Chris Clark for any questions or concerns you have with the repository.

# Chapter 2: The Web Framework and Database

## 2.1 The Development Environment

The AUM was developed using Ubuntu Server 16.04.2 with PostFix, PostgreSQL, OpenSSH, git, Python3.0, Gunicorn, Nginx, and Django 1.11. This guide does not cover how to download and install these programs. Nor does the AUM repository contain any files from these third party repositories. The following tutorials may be of assistance if you have never installed Ubuntu Server or any third party applications and still wish to deploy the AUM for your lab.

Ubuntu Installation Tutorial (https://tutorials.ubuntu.com/tutorial/tutorial-install-ubuntu-server#0)
Ubuntu Server Configuration Guide (https://help.ubuntu.com/lts/serverguide/)
- PostFix Service Guide (https://help.ubuntu.com/lts/serverguide/postfix.html)
- Git Version Control (https://www.digitalocean.com/community/tutorials/how-to-install-git-on-ubuntu-16-04)
- Environment Installation (https://www.digitalocean.com/community/tutorials/how-to-set-up-django-with-postgres-nginx-and-gunicorn-on-ubuntu-16-04)

## 2.2 The Production Environment

Deploying the AUM to a production environment is easy. Follow these high level steps to deploy and begin using the AUM:
1. Start with a fresh installation of the Development Environment on the production server you wish to use.
2. Clone the AUM repository to ./aum
3. Check out and edit ./aum/aum/settings.py to change the following settings:
a. SECRET_KET: Edit this to any randomly generated value. The current value is both insecure and only pseudorandom. The current value was used in the development environment and stored in the repository, every person with access to the repo has access and knowledge of that specific seret_key.
b. ALLOWED_HOSTS: Edit this to include your domain host entries
c. DATABASES: Edit USER, and PASSWORD with the PostgreSQL superuser information you created for your database.
4. Save and Check In settings.py
5. Reboot your server

If you have properly configured and installed all necessary applications, you should now be able to navigate a web browser to your management URL and begin use the AUM.

# Chapter 3: The Station Module

## 3.1 How to connect the module to the Wifi

The Station Module will automatically try to connect to the last known good Wifi. If it cannot connect, it will restart itself and set up an Access Point called AUM_Station_Module. The AP has a captive portal, so anytime you connect, you will be redirected to the config page. This mode can also be accessed at any time by holding down the “logout” button for a few seconds while cycling power or doing a reset.

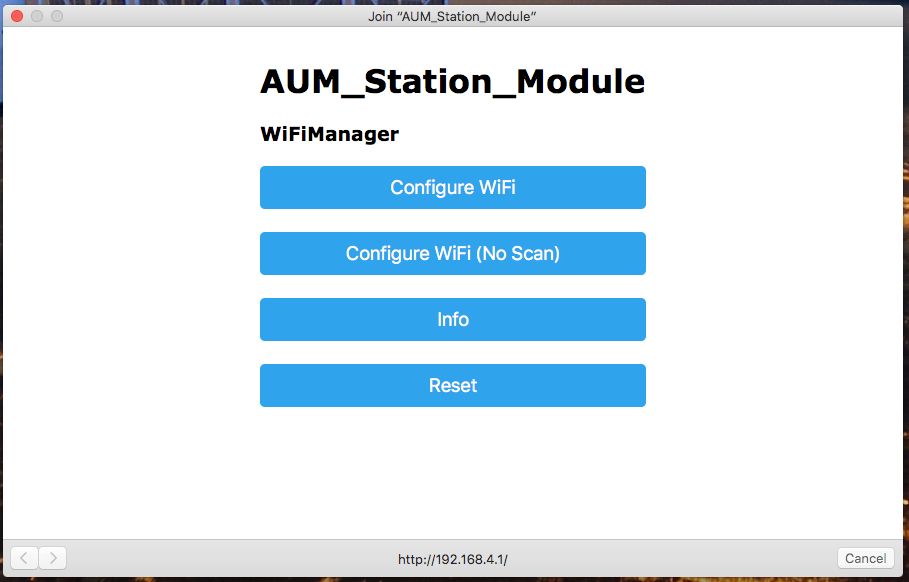
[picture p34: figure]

## Captive Portal Page

-select “Configure WiFi”

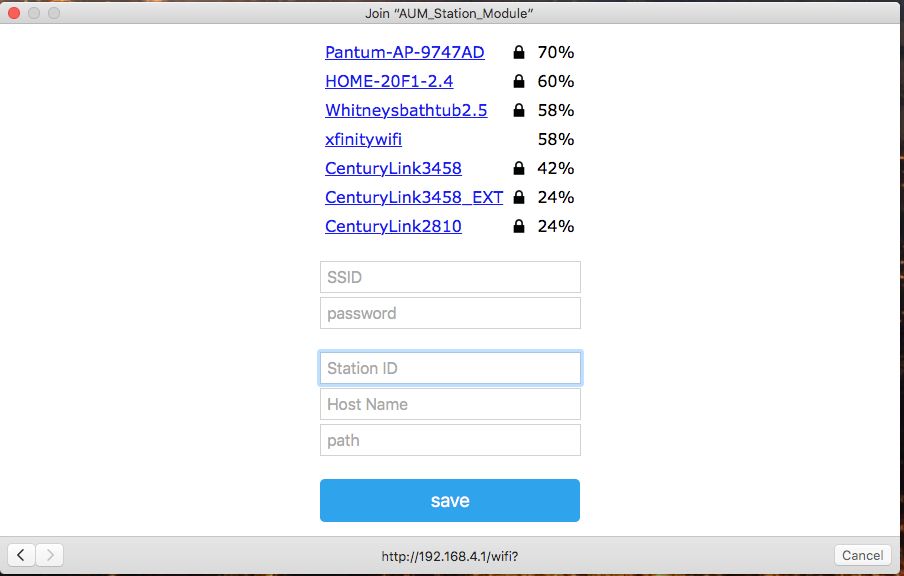
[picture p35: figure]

## Configuration Page

-Select your network
-Fill in password
-Fill in station module ID
-Fill in host name.
Ex: aummanage.com
-Fill in path.
Ex: \aum

-click save and the unit will restart

If the network you are trying to connect to requires a username and a password, then you must contact the network administrator and register the station module’s MAC address. Usernames and passwords are not supported on this device. To find the Station Module’s MAC address:
- In the captive portal, Click on info. The Station MAC is listed.

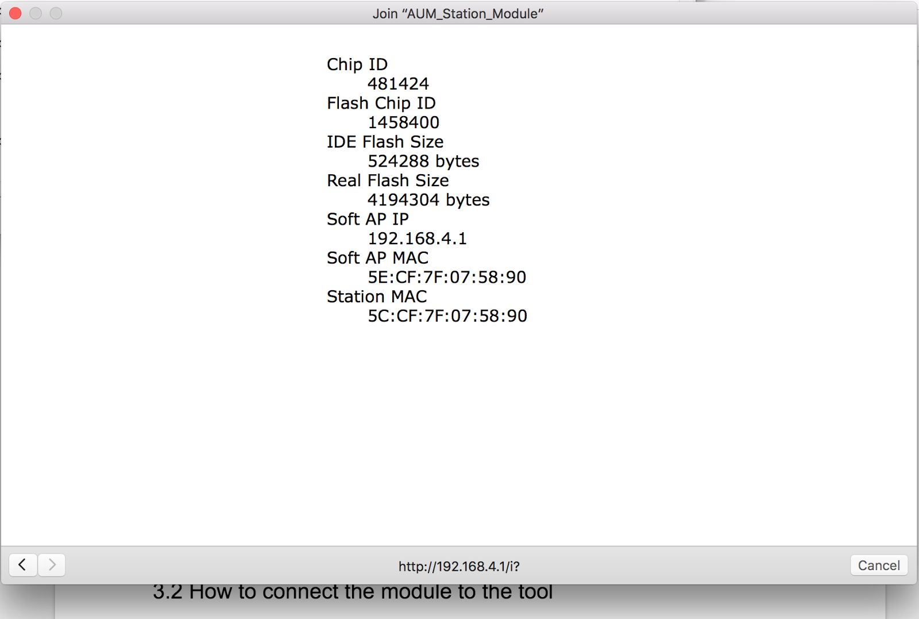
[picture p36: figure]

For PSU: Browse to https://intranet.pdx.edu/oit/internet-device-registration and fill out a Internet Device Registration request.

## 3.2 How to connect the module to the tool

The module controls power to the tool, and therefore “access” through an external isolated relay such as the PST2. The Station Module output can only supply up to 6mA, so a low power draw relay must be used.

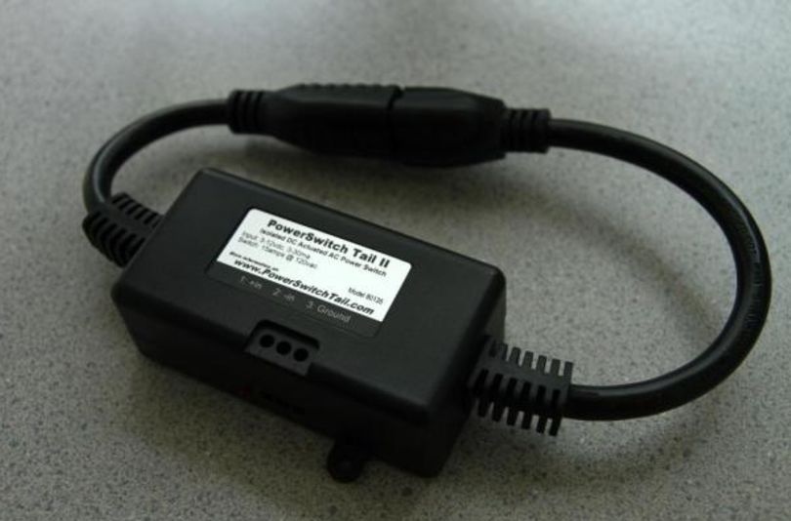
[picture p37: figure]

## 3.3 How to link the module to the database

- See Adding a Station Module

## 3.4 How to add a user to the Authorized User list for a tool

To authorize a new user with a station module:
- An authorized manager will hold the button down and scan their badge.
- A blinking green light will indicate that the new user may scan their badge.
- The Station module will link the user’s RFID with the Station Module.
- This process may take several seconds.
- When the LED returns to a solid green, the user is now authorized to use the tool.

Alternatively you may authorize the user through the User Interface, see Adding a user to the Authorized User list.

## 3.5 How a user logs into the tool

A user logs into a tool, and thereby gains access, by swiping their badge across the RFID reader. The Station Module will beep to acknowledge that a card was read, and flash green once. After the Station Module receives a reply from the database, it will emit another beep and either show a solid green LED on the SM, and switch power to the tool on, or emit a series of beeps, and remain showing a solid red LED to indicate that the user is not on the Authorized User list.

## 3.6 How a user logs out of the tool

A user logs out by pressing the button on the front of the SM. If another user scans in while the tool is powered on, and they do not have authorization to use the tool, the station module will power the tool off and deny the user access to the tool.

# Chapter 4: The User Interface

The User Interface is still under development. More detailed instructions will be included as part of later revisions to this document. All pages are not final and may be subject to change.

During Development, navigate to www.aummanage.com and use your credentials to login.
The sidebar navigation allows you to easily flow from one task to another. Simply select the task you wish to carry out and fill in the accompanying form. After you have submitted your form, a message is displayed letting you know if your submission experienced any errors.

This is the default pages for the AUM User Interface depend on the current user’s access level. Upon logging in, a User will be redirected to their profile page, if the user has Manager or higher access, they will be redirected to the “Add User” page.

For shorthand, Manager+ indicates a user that has at least Manager level access.

## 4.1 Site Navigation

Site Navigation as seen by a Superuser.

The site navigation sidebar allows you to jump from any page to another page. Simply click the desired destination and you will be redirected to that correct page.
- If any page is viewed by an Anonymous User or User, only “Logout” is visible.
- If any page is viewed by a Manager or Admin “Database Admin” will not be shown.
- If any page is viewed by an Owner or Superuser, all nav buttons will be shown

## 4.2 Users

The site will have multiple different access levels depending on internal permissions.
- The Anonymous User: This level of user is for a brand new person who has never made an account before. The level is used during the initial stages of user creation and does not require a login.
- The User: The lowest level of access. They may access their user profile and edit information contained within in.
- The Manager: The first level and most extensive of admin access. They may:
- Add, edit, and delete users.
- Add, edit, and delete Station Modules.
- Add, edit, and delete Authorized User entries.
- Run and export reports.
- The Admin: The second level of admin access. They may:
- Perform any Manager action
- Edit the ‘is_manager’ permission for a user.
- The Owner: The third level of admin access. They may:
- Perform any Admin action.
- Edit the ‘is_admin’ permission for a user.
- Backup and Restore the AUM Database.
- The Superuser: The highest level of admin access. They may:
- Perform any action.
- A Superuser has every permission and every access.

### 4.2.1 Adding a user

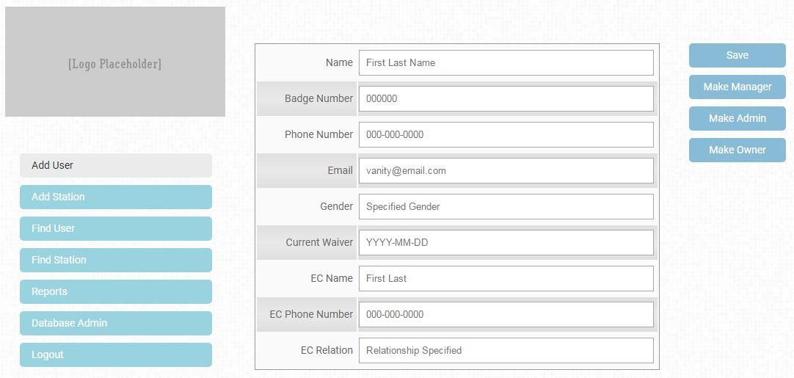
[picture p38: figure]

Page as seen by a Superuser.

To add a user, fill in all required information, and click “Save”.

There are two paths to this page:
- For an Anonymous User, click “New User” from login page.
- For Manager+, click “Add User” from the sidebar.

Page accessibility:
- This page is not visible to a User.
- If the page is viewed by an Anonymous User or Manager, only “Save” will be visible.
- If the page is viewed by an Admin, “Make Manager” will also be visible.
- If the page is viewed by an Owner, “Make Admin” will also be visible.
- If the page is viewed by a Superuser, “Make Owner” will also be visible.

### 4.2.2 Editing a user

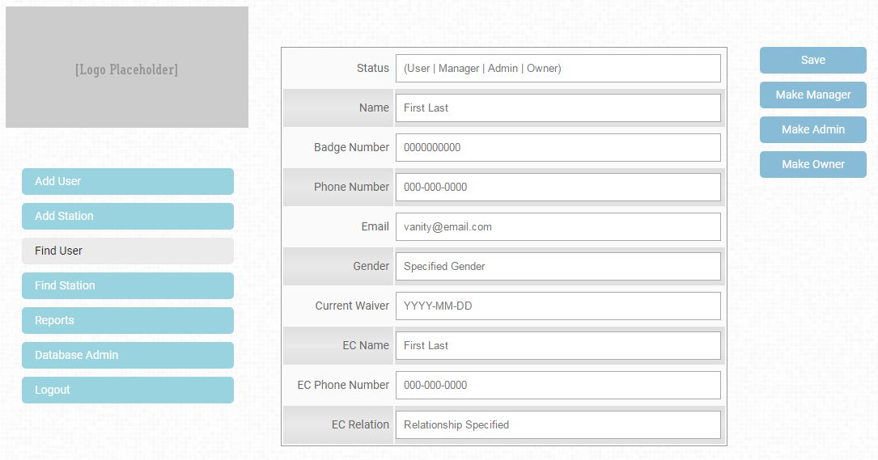
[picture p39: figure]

Page as seen by a Superuser.

To edit a user, fill in all required information, and click “Save”.

There are two paths to this page.
- For a User, press the “Edit Profile” button from their profile page.
- For a Manager+, use the sidebar to “Find User”. Once the desired user is located, press the “Edit User” button.

Page accessibility:
- This page is not visible by an Anonymous User.
- If the page is viewed by a User or Manager, only “Save” will be visible.
- If the page is viewed by an Admin, “Make Manager” will also be visible.
- If the page is viewed by an Owner, “Make Admin” will also be visible.
- If the page is viewed by a Superuser, “Make Owner” will also be visible.

### 4.2.3 Deleting a user

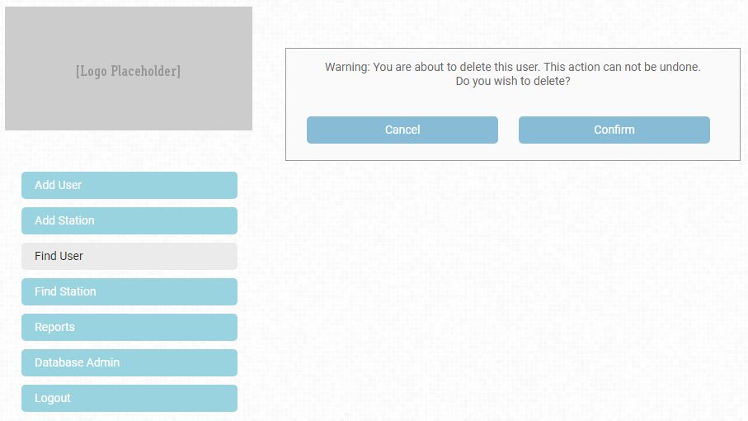
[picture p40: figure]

Page as seen by a Superuser.

To delete a user, click “Confirm”.

There is a single path to this page:
- Use the sidebar to “Find User”. Once the desired user is located, press the “Delete User” button.

Page accessibility:
- This page is only visible to Manager+.

### 4.2.4 Adding a user to the Authorized User list

Please see Adding a user to an Authorized User list

### 4.2.5 Searching for a User

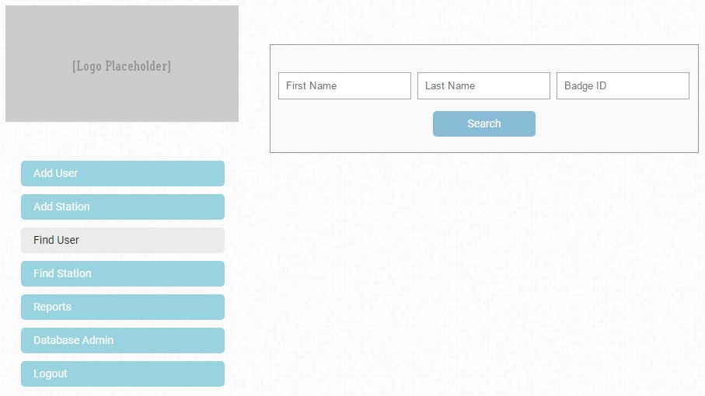
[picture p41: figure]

Page as seen by a Superuser.

To find a user, fill in all known information, and click “Search”.

There is a single path to this page:
- Use the sidebar to “Find User”.

Page accessibility:
- This page is only visible to Manager+.

## 4.3 Station Modules

### 4.3.1 Adding a Station Module

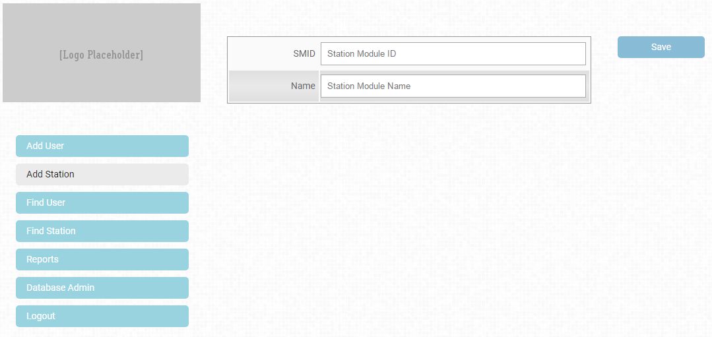
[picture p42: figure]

Page as seen by a Superuser.

To add a Station Module, fill in all required information, and click “Save”.

There is a single path to this page:
- Use the sidebar to “Add Station”.

Page accessibility:
- This page is only visible to Manager+.

### 4.3.2 Editing a Station Module

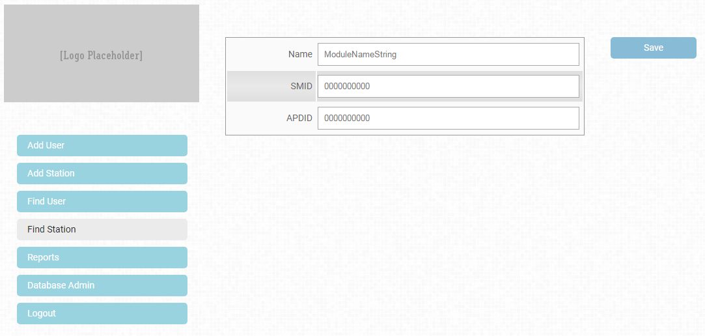
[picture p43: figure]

Page as seen by a Superuser.

To edit a Station Module, fill in all required information, and click “Save”.

There is a single path to this page:
- Use the sidebar to “Find Station”. Once the Station Module is located, press the “Edit SM” button.

Page accessibility:
- This page is only visible to Manager+.

### 4.3.3 Deleting a Station Module

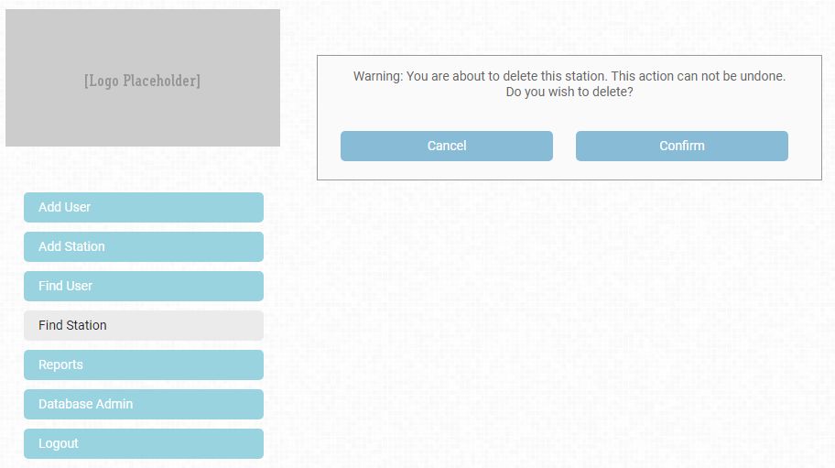
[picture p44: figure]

Page as seen by a Superuser.

To delete a Station Module, click “Confirm”.

There is a single path to this page:
- Use the sidebar to “Find Station”. Once the Station Module is located, press the “Delete SM” button.

Page accessibility:
- This page is only visible to Manager+.

### 4.3.4 Searching for a Station Module

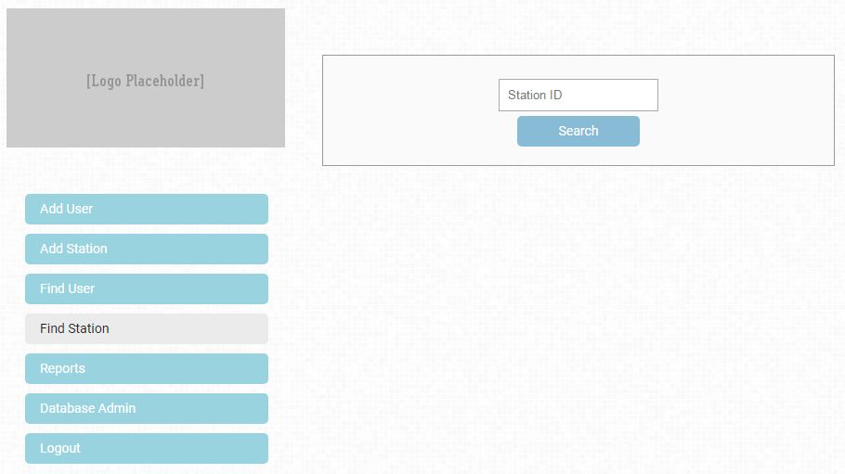
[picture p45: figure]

Page as seen by a Superuser.

To find a station module, fill in all required information, and click “Search”.

There is a single path to this page:
- Click “Find Station” from the sidebar.

Page accessibility:
- This page is only visible to Manager+.

## 4.4 Authorized User Lists

### 4.4.1 Adding a user to an Authorized User list

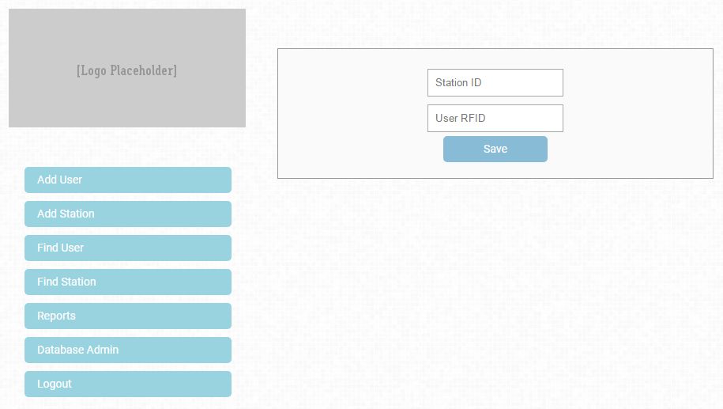
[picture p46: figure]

Page as seen by a Superuser.

To add a user to the Authorized User list for a specific Station Module, fill in all required information, and click “Save”.

There are two paths to this page:
- From “Find User”. Search for the desired User. Once the user is located, press the “Add User to SM” button.
- From “Find Station.” Search for the desired Station Module. Once the Station Module is located, press the “Add User to SM” button.

Page accessibility:
- This page is only visible to Manager+.

### 4.4.2 Removing a user from an Authorized User list

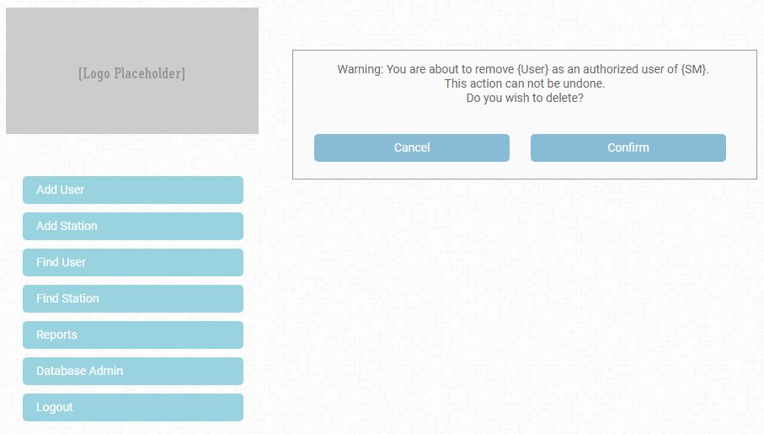
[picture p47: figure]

Page as seen by a Superuser.

To delete a user from the Authorized User list for a specific Station Module, click “Confirm”.

There are two paths to this page:
- From “Find User”. Once the desired user is located, press the “Remove User from Tool” button. Enter the “Station Module ID” and press the “Remove User” button.
- From “Find Station.” Once the desired Station Module is located, press the “Remove User from Tool” button. Enter the user’s RFID and press the “Remove “User” button.

Page accessibility:
- This page is only visible to Manager+.

## 4.5 Reports

### 4.5.1 Running a report

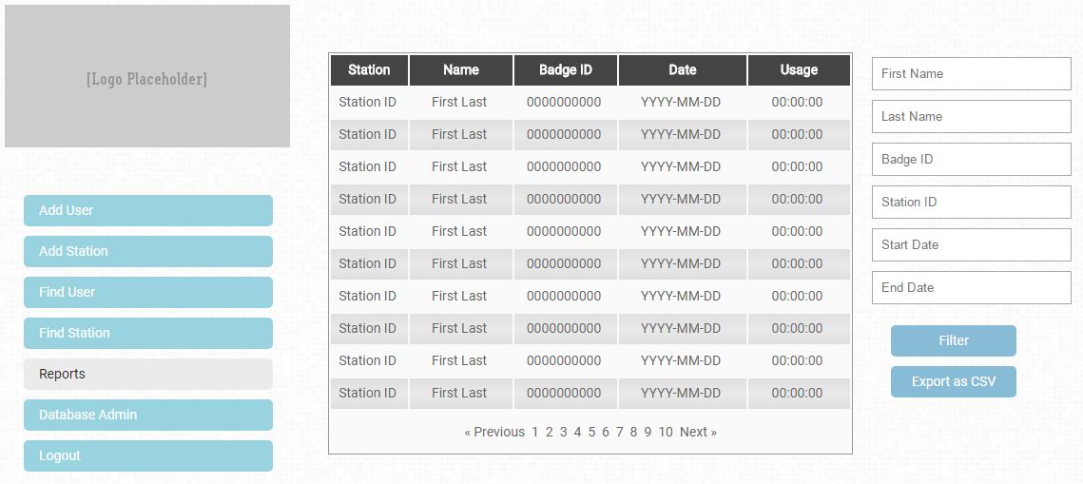
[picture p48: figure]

Page as seen by a Superuser.

To run a report, fill in all desired filter information, and click “Filter”.

There is a single path to this page:
- Click “Reports” from the sidebar.

Page accessibility:
- This page is only visible to Manager+.

### 4.5.2 Exporting a report

Page as seen by a Superuser.

To export a report, fill in all desired filter information, and click “Export as CSV”. You may also click
“Export as CSV” from any filtered report display page.

There are two paths to this page:
- Click “Reports” from the sidebar.
- Click “Reports” from the sidebar. Then click “Filter”.

Page accessibility:
- This page is only visible to Manager+.

### 4.5.3 Report Examples

Use By Station Module

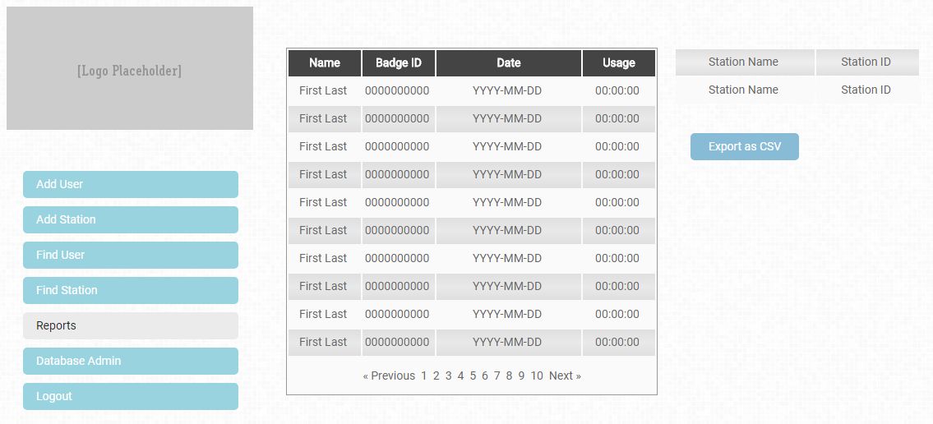
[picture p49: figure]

Page as seen by a Superuser.

This report displays the specific usage for a given Station Module.

Page accessibility:
- This page is only visible to Manager+.

Use by User

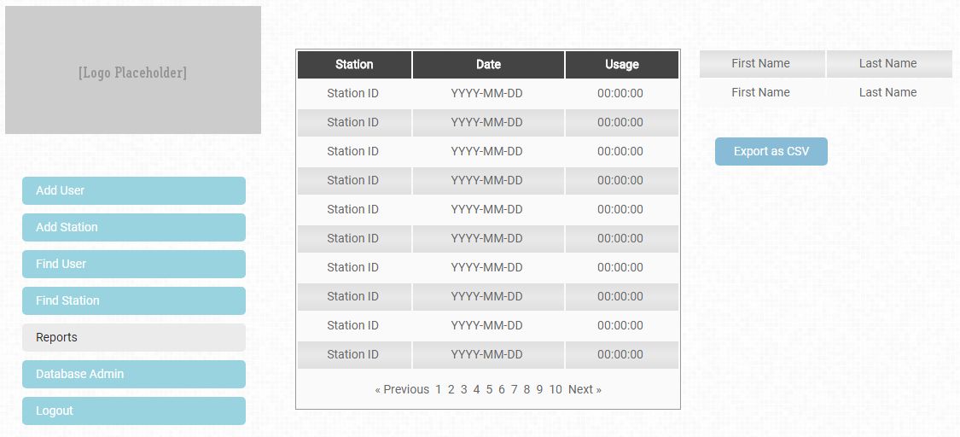
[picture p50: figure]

Page as seen by a Superuser.

This report displays the specific usage for a given User.

Page accessibility:
- This page is only visible to Manager+.

Use by Date

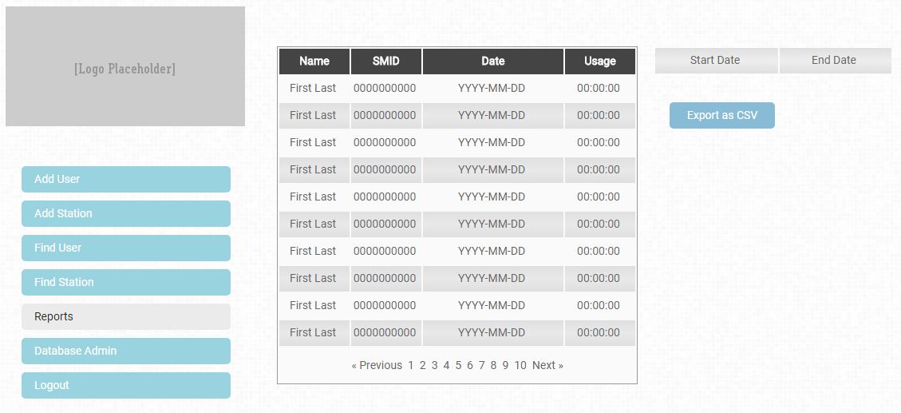
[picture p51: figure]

Page as seen by a Superuser.

This report displays the specific usage for a given Date range.

Page accessibility:
- This page is only visible to Manager+.

Use by User and Station Module

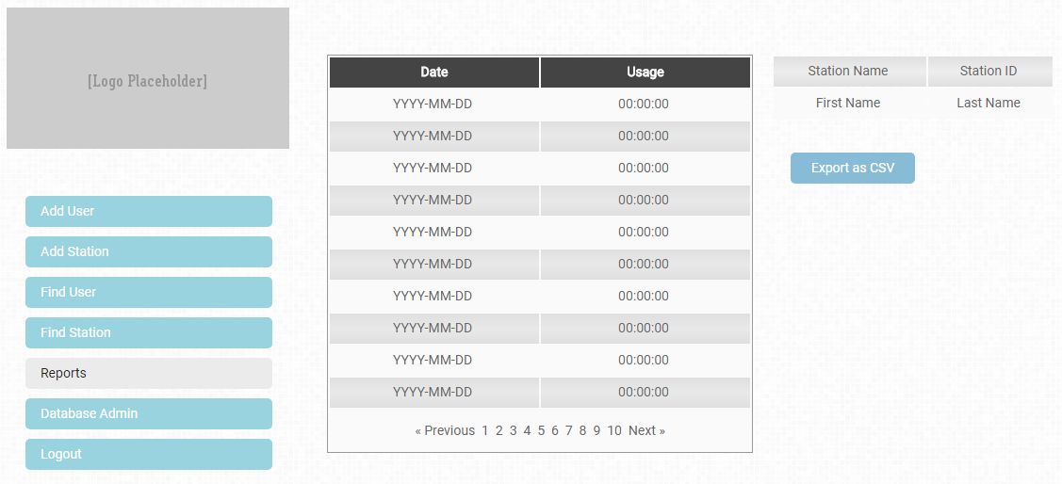
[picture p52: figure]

Page as seen by a Superuser.

This report displays the specific usage for a given User and Station Module.

Page accessibility:
- This page is only visible to Manager+.

Use by Station Module and Date

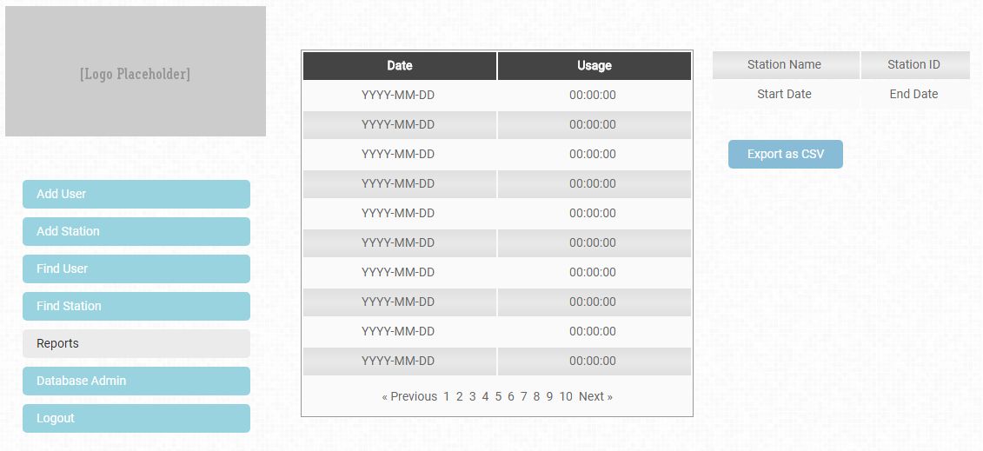
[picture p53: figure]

Page as seen by a Superuser.

This report displays the specific usage for a given Station Module and Date range.

Page accessibility:
- This page is only visible to Manager+.

Use by User and Date

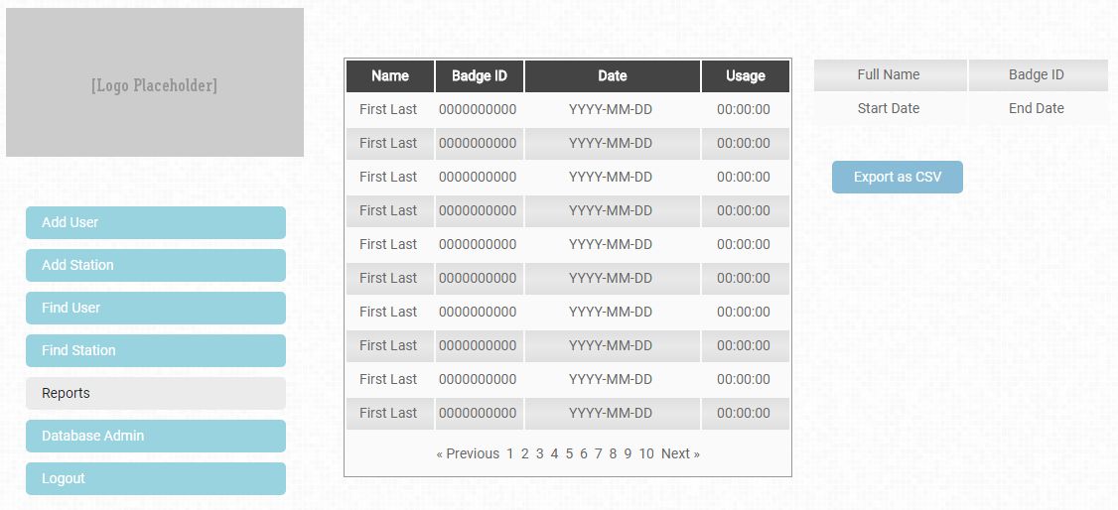
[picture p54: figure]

Page as seen by a Superuser.

This report displays the specific usage for a given User and Date range.

Page accessibility:
- This page is only visible to Manager+.

Use by User, Station Module, and Date

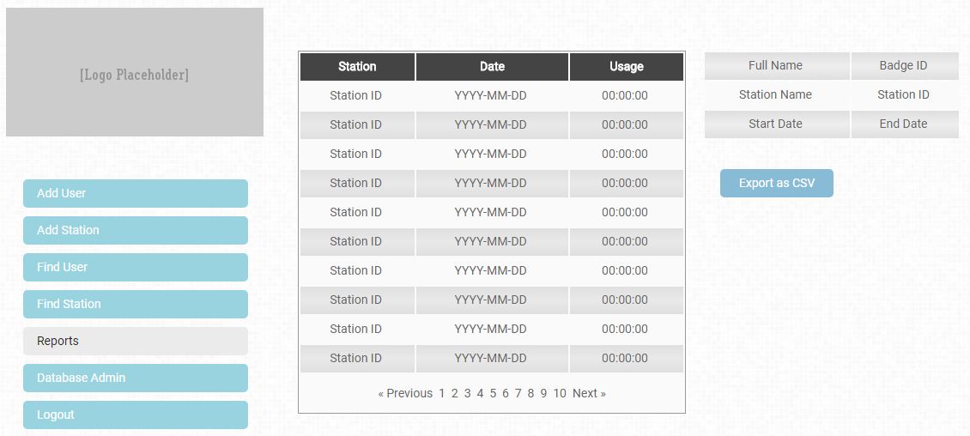
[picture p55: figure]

Page as seen by a Superuser.

This report displays the specific usage for a given User, Station Module, and Date range.

Page accessibility:
- This page is only visible to Manager+.

## 4.6 Database Administration

### 4.6.1 Backup Database

Page as seen by a Superuser.

The database backup feature has not been implemented yet.

Page accessibility:
- This page is only visible to Owner and Superuser.

### 4.6.2 Restore Database

Page as seen by a Superuser.

The database restore feature has not been implemented yet.

Page accessibility:
- This page is only visible to Owner and Superuser.

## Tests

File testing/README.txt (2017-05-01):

Purpose: Top Test Software Directory

Comments: Do not place bare executables or test software in this folder. 
Individual projects should start by creating their own folder, appropriately 
titled, where their specific files may be housed.

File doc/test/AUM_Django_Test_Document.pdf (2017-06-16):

# MAY 2, 2017

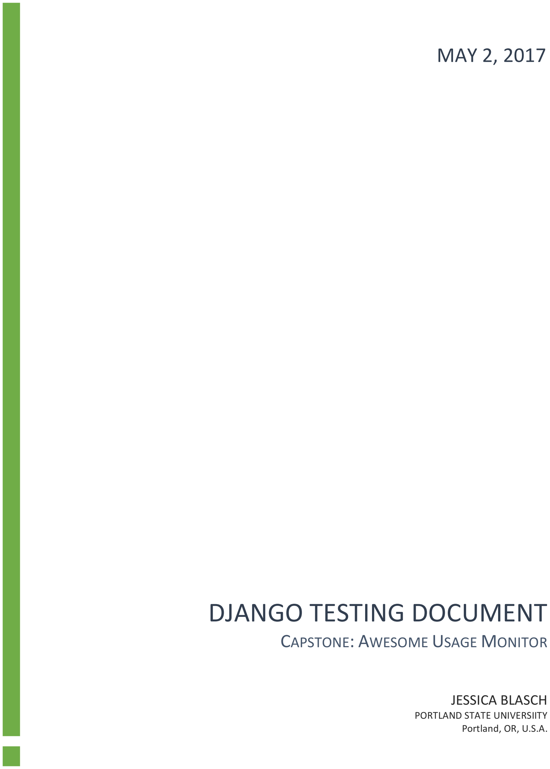
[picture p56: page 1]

# DJANGO TESTING DOCUMENT

## CAPSTONE: AWESOME USAGE MONITOR

## JESSICA BLASCH

PORTLAND STATE UNIVERSIITY Portland, OR, U.S.A.

Version 1.0

Version History

Version # | Revision Date | Responsible Party | Reason
1.0 | 02 May, 2017 | Jessica Blasch | Initial creation of source document

## Table of Contents

## Introduction

## Read Me

I have written this document assuming the reader has little or no prior experience with Django. I, for one, am a beginner at using the Python language having written only one program in it prior. I had no prior experience using Django (or anything like it), before the start of this project, and absolutely zero experience writing and running tests.

If you, like myself, have little or no prior experience with Python, Django, and/or testing, it can be extremely daunting how to even begin. Django documentation has tutorials to get you acquainted with the Django environment and they have a tutorial on testing. I think the tutorials are okay in so much that they let you touch Django and get some preliminary fighting out of the way, but that’s about all you do in them; they have you robot through instructions without sufficient explanation about the set up and code they have you copy/pasting.

All that being said, I highly recommend getting the Django documentation tutorials out of the way and moving on to bigger and better things. YouTube has a lot of Django testing tutorials that really walk you through the process. They, of course, all use very trivial examples, but, I think, are more helpful. One tutorial in particular that I am fond of is:

The Django Test Driven Development Cookbook: https://www.youtube.com/watch?v=41ek3VNx_6Q

This one really helped me “get out the gate”. I went ahead and put the tutorial into document format transcribing and adding images of what the host said and did as I worked through it. That document will accompany this document as a resource for anyone working on this project in the future. That way, you can go through the tutorial and later reference the accompanying document instead of scrolling through video trying to find something. As stated before, the examples used in many tutorials are trivial, so don’t expect that they will just hand you answers, but they can set you on the right path.

I have tried to differentiate between “instructions” and ”my side commentary” by using grayed text as commentary. You may see me use “django-admin” and “django-admin.py” for different instances. The reason for this is that they both work. Last, but not least, when a new test is created run it, edit as needed, and run it again until it passes. This will save you time trying to track down when and where things went south.

6/13/17: The headings starting with “Testing Views”, at this time, are incomplete. To date, the only testable file available in the git repository is the models.py file. I believe views, etc. are being created and will be uploaded soon, but not in time to test. I have one suggestion under “Testing Views”. The rest, I am commenting, but would highly recommend viewing the tutorial I cited and the source document I created for it as it relates to the additional headings.

6/15/17: Many files in the aum project have been updated. I have added the settings.py, models.py, and managers.py files to the test environment. Tests still pass. Project hand-off to the sponsor happens today.

## Integration of Product and Test Environments

For the initial project, there were multiple “teams” within our team; one person did circuit design and the programming of it, one person did the framework, and one person did the testing. This document covers what was done in the test environment. Integrating the test environment into the product package should be able to be accomplished by familiarizing oneself with this document’s procedures and then applying them inside the virtual environment for the AUM product. Some steps like creating a virtual environment and adding the app to the settings file may be skipped, since they will have already been done in the development of the AUM product.

## OS and Considerations

I am using a 2016 MacBook Pro with macOS Sierra version 10.12.4. Please note, the documentation for creating a virtual environment is what I found to work on my machine. It will be different, if you are using a machine that does not use OS X. You can do a general search engine query on how to set up a virtual environment, but I found that Django Girls has a pretty comprehensive list of instructions for several operating systems: https://tutorial.djangogirls.org/en/django_installation/ . Everything else should be the same.

## General Overview of Test Setup

### File and Folder Map

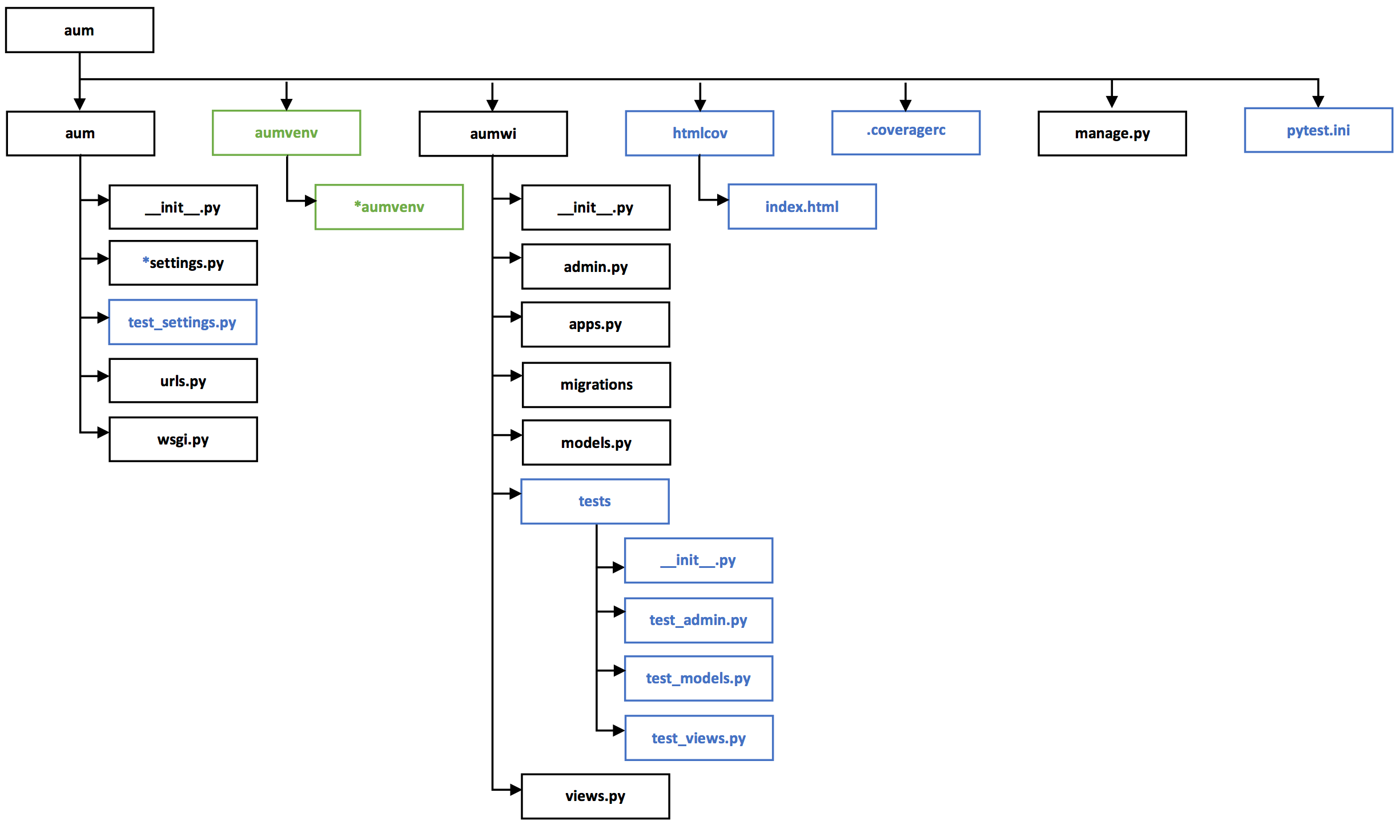
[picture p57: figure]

### File and Folder: Functions and Relations

aum (top level): This is the root folder for your project. Django documentation will instruct you to first create a folder to house your Django project. There are a couple ways to determine the final folder set up.

1. Use the folder you created for the project as the root folder and create set up within it.

From the terminal, cd into the folder and do an admin call to start the project within it. e.g. $ django-admin startproject aum .

Notes: Preferred method.
The period “ .” is crucial in the call. Using this method, the folder you created to house your project becomes the root folder and houses your settings and other folders/files directly inside it. This is the method I will use in the documentation.
2. Create a root folder and set up within the folder you created to house your project.

From the terminal, cd into the folder and do an admin call to start the project within it. e.g. $ django-admin.py startproject aum

Notes: I don’t care for this method.
The reason being that now there is yet another folder (not pictured) encompassing the project root and settings folders. It seems an unnecessary complication.

When working in the terminal, this is, generally speaking, the only folder you need to cd in to in order to work on the project. From this folder, you can create/activate your virtual environment and make changes to all other files and folders inside this folder without having to cd into them.

Notes: Name does not matter, but must be the name of the project initially, if you use method 2 above. Otherwise, it’s whatever you call it and is changeable.

aum (2nd level): This is the settings folder for the project that is automatically created when you start your Django project.

Notes: You cannot change the name, because it’s in the settings. It’s crucial this folder name matches between all people working on the project. It will be generated for you at the time you start your Django project.

aumvenv: This is the virtual environment folder that you create for the project. It’s not necessary, but it is highly recommended, because it allows you to create settings for the project (e.g. Python and Django versions) and isolate it so it will not affect other projects you may be working on.

Notes: Name does not matter. It’s whatever you call it, but it is static after.

aumwi: This is the app folder for the project that you create after you start your Django project.
e.g. $ django-admin.py startapp aumwi

Notes: It’s crucial this folder name matches the name being used by all people working on the project.

manage.py: The manage.py file is automatically created in each Django project. manage.py does the same thing django-admin does with a few extras (Django’s command-line utility for administrative tasks).

- - - The following items in the diagram denoted in blue have to do with the testing setup. - - -

Please note: Some items below are reliant upon doing pip installs in order to function. That is covered later in this document.

*aum/settings.py: The name of your app needs to be added to this file.

test_settings.py: You need to create this file. This is where the settings for the test database and testing email settings live.

tests: You need to create this folder and its contents. This folder replaces the “tests.py” file that Django automatically creates, when you start a new app. This is where your tests live. You need to create an “__init__.py” file for it. Models, views, forms, etc. and any other files you want to test will have their own test files you will need to also create within this folder.

htmlcov: This folder is created for you when you start running your tests. It houses a callable index file to show your test coverage.

.coveragerc: You need to create this file. This is a hidden file. It allows you to omit certain things from test coverage reports in order to keep them clean of information you don’t care about (e.g. items that are not testing related).

pytest.ini: You need to create this file. It tells pytest where your test settings live, allows you to stop migrations during testing and set the format the output of your coverage report.

## Code Editor

I have Canopy and Anaconda installed on my machine as well as Python 2.6, 2.7, and 3.6. However, Canopy is geared to use and interpret Python 2 (legacy). For this project, I will be using Atom, but here are a few different options.

PyCharm: https://www.jetbrains.com/pycharm/download/#section=mac

Gedit: https://wiki.gnome.org/Apps/Gedit#Download

Sublime Text 3: https://www.sublimetext.com/3

Atom: https://atom.io/

¬ Extremely powerful. Less suitable for a beginner.

¬ Open-source. Available for all operating systems.

¬ Free evaluation period. For all operating systems.

¬ Open-source. Created by GitHub. Available for Windows, OS X, and Linux.

## Set up Virtual Environment

The following assumes setup is done on a Mac under the home directory e.g. /Users/Name (where “Name” is the name of your login). If you are using a different machine, Django Girls has a good tutorial that covers multiple systems and potential problems under their Django installation page: https://tutorial.djangogirls.org/en/django_installation/

Further reading
Virtual environments: https://docs.python.org/3/tutorial/venv.htmlhttp://python-guide-pt-br.readthedocs.io/en/latest/dev/virtualenvs/Virtualenvwrapper: https://virtualenvwrapper.readthedocs.io/en/latest/
1. Install virtualenv and virtualenvwrapper

Command line:
$ pip3 install virtualenv
$ pip3 install virtualenvwrapper | ¬ I was unable to get virtual environment wrapper to work.
2. Set up a folder for the Django project (Do not call it “Django”) and create the virtual environment

Command line:
$ cd ~
$ mkdir test_aum
$ cd test_aum
$ python3 -m venv aumvenv | ¬ You may call it whatever you like. I used “aumvenv”.
3. Start virtual environment

Command line:
$ source aumvenv/bin/activate

You will know the virtual environment has been activated when the beginning of the command line displays (aumenv) at the beginning.

4. Make sure you have the latest version of pip

Command line:
(aumvenv) ~$ pip install --upgrade pip
5. Install Django

Command line:
(aumvenv) ~$ pip install django~=1.11.2 | ¬ This is the latest version used for initial testing. Use the most current version by omitting “~=1.11.2”, but make sure the tests still run.

## Project Test Environment Setup

1. Start new Django project

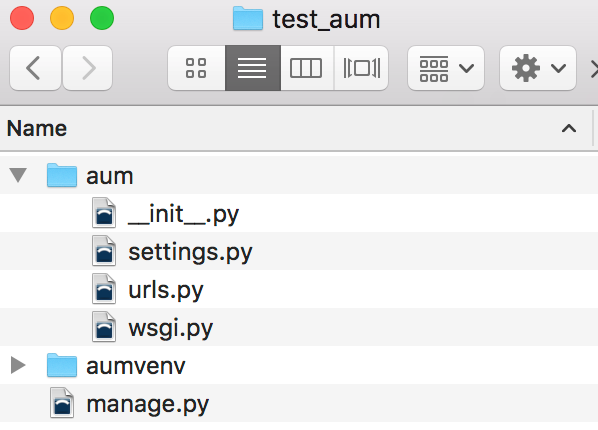
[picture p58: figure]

Command line:
(aumvenv) ~$ django-admin startproject aum .
2. Create a “test_settings.py” file in the settings folder test_aum/aum

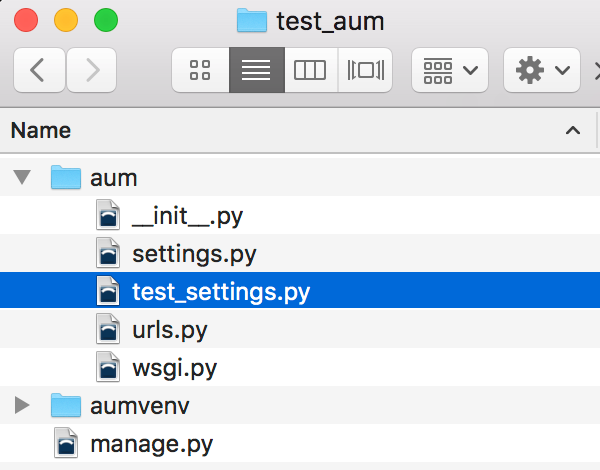
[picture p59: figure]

Command line:
(aumvenv) ~$ touch aum/test_settings.py

Add the following code:

#test_settings.py

from .settings import *

DATABASES = {
"default": {
"ENGINE": "django.db.backends.sqlite3", "NAME": "memory",
}
}

EMAIL_BACKEND = 'django.core.mail.backends.locmem.EmailBackend'

Instead of using a Postgres or MySQL db, we are using an “in memory” sqlite db which makes tests fast. Every test will destroy the db and create a new one. If you do that with a db that needs I/O operations on a hard drive, it’s going to be slow. In-memory is a good way around that.

Email backend is set to local memory, so that you don’t send real emails while running tests.

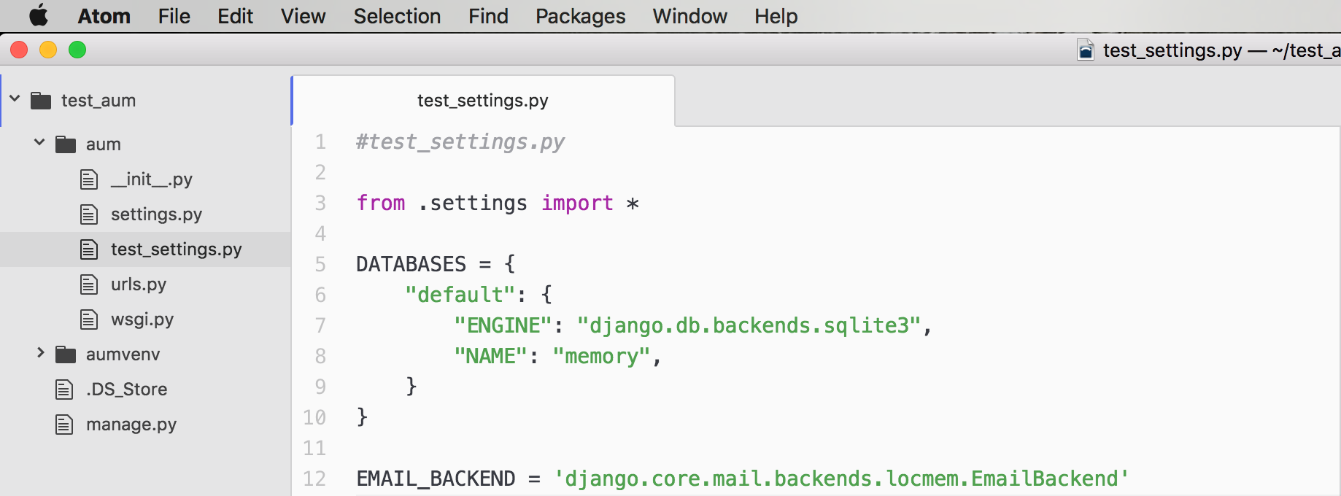
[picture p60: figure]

3. Install pytest & plugins and create “pytest.ini” in the root folder capstone_aum

Install a few Python libraries:

Command line:
(aumvenv) ~$ pip install pytest (aumvenv) ~$ pip install pytest-django (aumvenv) ~$ pip install pdbpp
(aumvenv) ~$ pip install pytest-cov (aumvenv) ~$ deactivate
(aumvenv) ~$ source aumvenv/bin/activate

* If you get an error after installing pdbpp install it again. I didn’t end up using it, but it could prove very helpful later.

pytest has lots of plugins. You can use them by just installing them. https://pypi.python.org/pypi/pytest/3.0.7

pytest-django is a plugin in pytest https://github.com/pytest-dev/pytest-django

pdb++ is a drop-in replacement for pdb. It’s for setting breakpoints into your tests and then you’ll be able to use the pdb++ debugger which is nicer than the original, because it has colors and code completion. https://pypi.python.org/pypi/pdbpp/

pytest coverage helps you generate a coverage report. When we run our tests, it generates a bunch of html files. You can see all your code files and the percentage of lines in the file that have been hit by your tests.
https://pypi.python.org/pypi/pytest-cov/2.4.0

100% test coverage doesn’t mean you have good tests. However, without 100% test coverage it’s easy to get in a situation where sloppy fixes add up over time and your test coverage goes down.

After you install all the libraries, you need to deactivate your virtual environment and then reactivate it (as shown). Otherwise, it will throw weird errors.

This file needs to go next to the manage.py file:

Command line:
(aumvenv) ~$ touch pytest.ini

Add the following code:

[pytest]
DJANGO_SETTINGS_MODULE = aum.test_settings addopts = --nomigrations --cov=. --cov-report=html

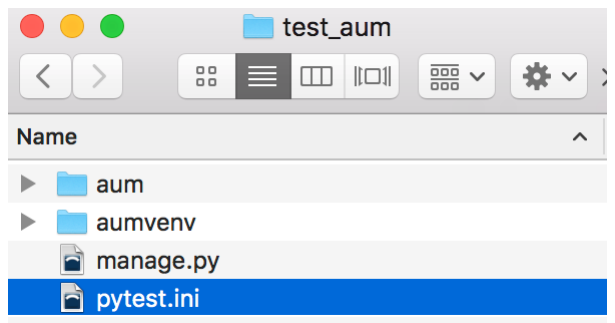
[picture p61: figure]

¬ Tell it where the test settings file is
¬ Add more arguments to the command argument

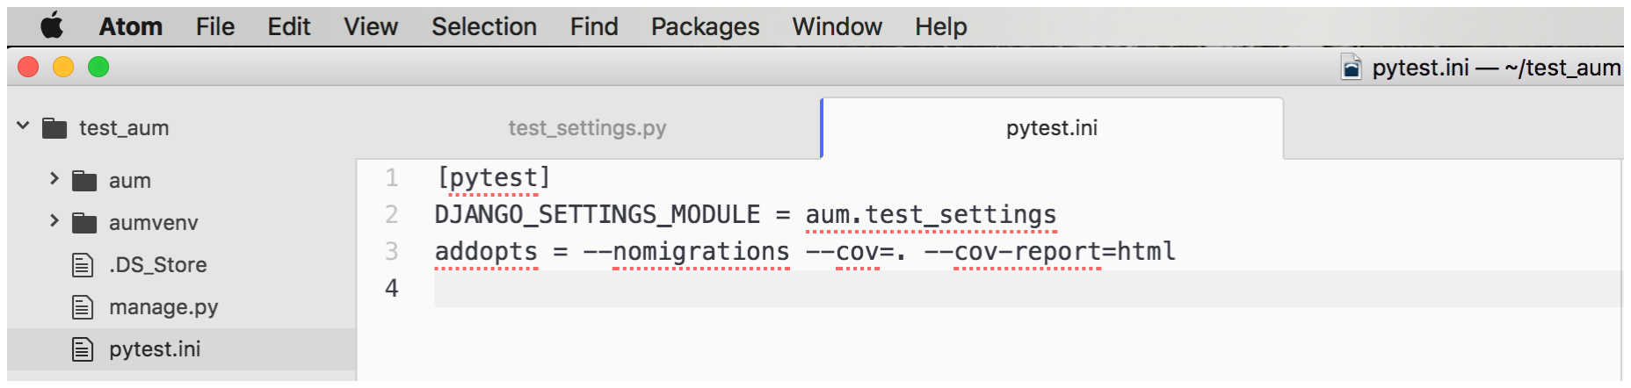
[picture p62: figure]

Now try running it:

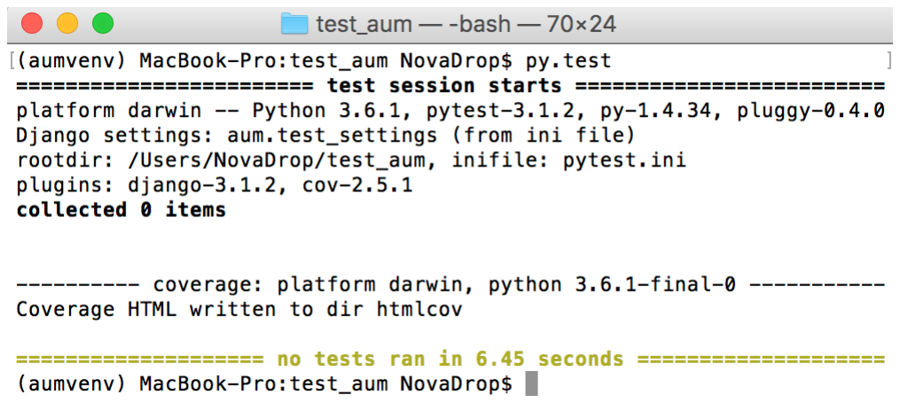
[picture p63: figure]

Command line:
(aumvenv) ~$ py.test

4. Create a “.coveragerc” file

Command line:
(aumvenv) ~$ touch .coveragerc

This is a hidden file, so it’s easy to forget it exists. It will not show up in normal file searches. However, without it, the coverage report will look messed up. The html file will be a huge list where half of the files don’t even interest you. Because you don’t test files added to this list it means the coverage will be 0%, which will lower your total coverage and you want your total coverage to be 100%. So, whenever you have a file you don’t care about, you need to add it to this list so that it gets removed from the coverage report.

Add the following code:

[run]
omit =
*apps.py,
*migrations/*,
*settings*,
*tests/*,
*urls.py,
*wsgi.py,
*manage.py,
*aumvenv/*
*aum/__init__.py,
*aumwi/__init__.py,

¬ What this code means is that in certain files you don’t care about the test coverage.

e.g.
Don’t test migrations, because they’re auto-generated. Don’t test the test files, because that’s over kill. Don’t test virtual environment files, because it’s not your actual project, etc.

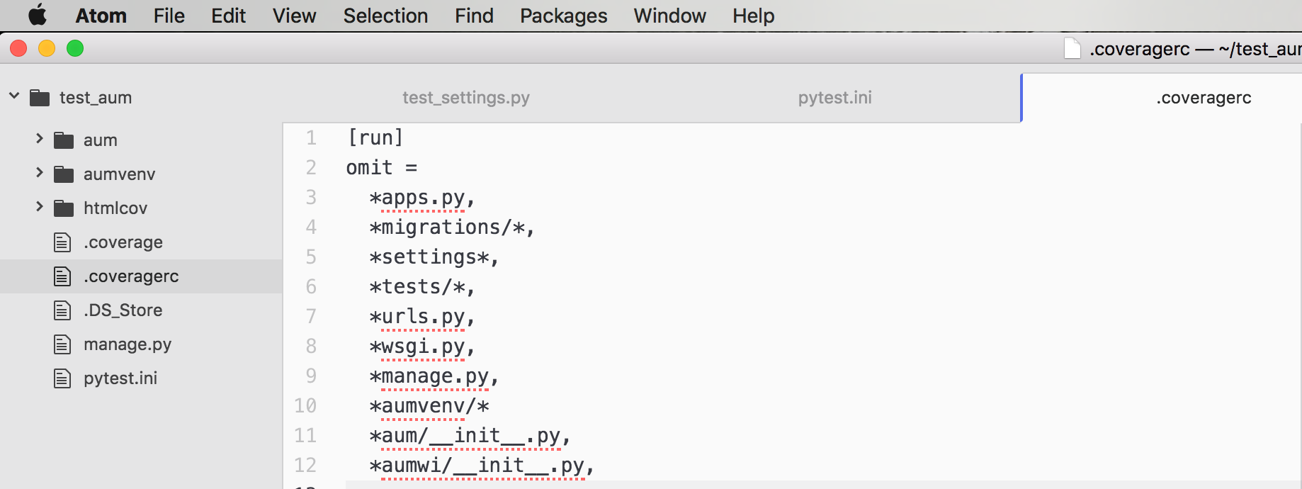
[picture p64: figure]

5. Install mixer

Command line:
(aumvenv) ~$ pip install mixer mixer is a tool for helping you create test fixtures.

e.g.
Say you have a view that shows your user profile and you want to test it. That view can only be called by giving the primary key of that user. There needs to be something in the database so this view can even be called, because the first thing this view is going to try to do is fetch that model from the database. If it’s empty it will throw a 404 error.

If the profile model has 20 fields, mixer will put random values into each of these fields. Your tests may pass and then one day fail because mixer put something into your tests you never thought about. So, it can help you find test cases you never thought about.

6. Create the folder set up for writing tests
- Remove the “tests.py” file and create a “tests” folder instead
- Each Django app will have a “tests” folder
- Each code file will have a tests file e.g “test_models.py”

Command line:
(aumvenv) ~$ django-admin startapp aumwi
(aumvenv) ~$ rm aumwi/tests.py
(aumvenv) ~$ mkdir aumwi/tests (aumvenv) ~$ touch aumwi/tests/__init__.py

¬ Create “aumwi” app in the root folder
¬ Delete the “tests.py” file in the “aumwi” folder ¬ Create “tests” folder in the “aumwi” folder
¬ Create an ‘__init__.py’ “aumwi/tests” folder

To ensure we’re on the same page, here is a view of the aumwi folder before and after alterations:

aumwi folder before alterations: | aumwi folder after alterations:

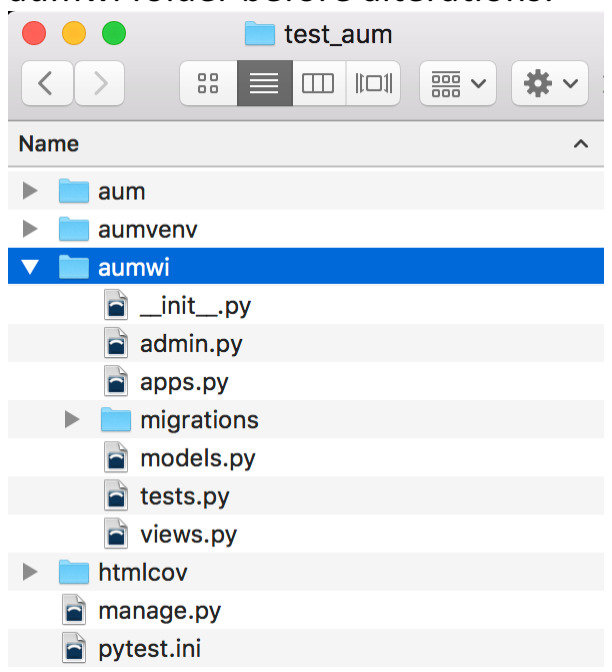
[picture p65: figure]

7. Add the “aumwi” app to the aum/settings.py file


Import the settings.py file from Capstone-LID_Tracking/aumwi/models.py (last version available: 5/15/17)

® This should be a simple cut/paste over the code auto-generated in the test environment settings.py file. ® If unable to do this, at a minimum, add the “aumwi” app manually like below:


At this point, we are set up to begin testing

!!! Important !!!
py.test will:
- Find all files called “test_.py”
- Execute all functions called “test_()*” on all classes that start with “Test*”

## Testing Models

1. Import models.py from Capstone-LID_Tracking/aumwi/models.py (last version available: 5/15/17)

This is a simple cut/paste.

2. Create “managers.py” file and import managers from Capstone-LID_Tracking/aumwi/managers.py

Command line:
(aumvenv) ~$ touch aumwi/managers.py


Then cut/paste the managers.py file from Capstone-LID_Tracking/aumwi/managers.py into the file just created.

3. Create “test_models.py” file in aumwi/tests folder

Command line:
(aumvenv) ~$ touch aumwi/tests/test_models.py

Add the following code:

# test_models.py

import pytest # This is the test interpreter. Must install pytest to use.
pytestmark = pytest.mark.django_db # Use pytest marks to tell pytest-django your test needs database access.
# Must install pytest-django to use.

# http://pytest-django.readthedocs.io/en/latest/database.html from aumwi.models import User, ModuleList, AuthUser, UsageLog # mixer doesn't need this. For use with e.g. users = User.objects.all() from django.test import TestCase # Allows use of assertEqual

from mixer.backend.django import mixer # Test fixture creator. Must install mixer.
from django.db import IntegrityError, transaction

class TestUser(TestCase):
def test_init(self):
obj = mixer.blend('aumwi.User')
users = User.objects.all()
self.assertEqual(len(users), 1), 'Should create a User instance.'

def test_unique_fields(self): #Exception raised when the relational integrity of the database is affected with self.assertRaises(IntegrityError):
# roll back transaction to a clean state before letting the IntegrityError bubble up

with transaction.atomic():
# This code executes inside a transaction.

user1 = mixer.blend('aumwi.User', id = '5dad0428-1da1-4d6d-8cd2-ca88ad23a6f6') user2 = User(
id = '5dad0428-1da1-4d6d-8cd2-ca88ad23a6f6',
username = 'tinyrobotarmy',
full_name = 'Your Mom',
email = 'dontpantsme@gmail.com',
rfid = 9223372036854775807,
)
user2.save(force_insert = True), 'Should raise IntegrityError: User.id' with self.assertRaises(IntegrityError):
with transaction.atomic():
user1 = mixer.blend('aumwi.User', username = 'SilverwareGolem')
user2 = mixer.blend('aumwi.User', username = 'SilverwareGolem'),'Should raise IntegrityError: User.username' with self.assertRaises(IntegrityError):
with transaction.atomic():
user1 = mixer.blend('aumwi.User', email = 'dontpantsme@gmail.com')

user2 = mixer.blend('aumwi.User', email = 'dontpantsme@gmail.com'),'Should raise IntegrityError: User.email' with self.assertRaises(IntegrityError):
with transaction.atomic():
user1 = mixer.blend('aumwi.User', rfid = '922337203685477580')
user2 = mixer.blend('aumwi.User', rfid = '922337203685477580'), 'Should raise IntegrityError: User.rfid'

def test_empty_fields(self): #Exception raised when the relational integrity of the database is affected
'''
I am not testing User.id here. This test does not work for the id,
I think because the system is designed to assign one at the time of saving.
'''
with self.assertRaises(IntegrityError):
# roll back transaction to a clean state before letting the IntegrityError bubble up

with transaction.atomic():
# This code executes inside a transaction.

obj = mixer.blend('aumwi.User', username = None),'Should raise IntegrityError: User.username' with self.assertRaises(IntegrityError):
with transaction.atomic():
obj = mixer.blend('aumwi.User', email = None),'Should raise IntegrityError: User.email'
with self.assertRaises(IntegrityError):
with transaction.atomic():
obj = mixer.blend('aumwi.User', rfid = None), 'Should raise IntegrityError: User.rfid'

class TestModuleList(TestCase):
def test_init(self):
obj = mixer.blend('aumwi.ModuleList')
modules = ModuleList.objects.all()
self.assertEqual(len(modules), 1), 'Should create a ModuleList instance.'

def test_unique_fields(self): #Exception raised when the relational integrity of the database is affected with self.assertRaises(IntegrityError):
# roll back transaction to a clean state before letting the IntegrityError bubble up

with transaction.atomic():
# This code executes inside a transaction.

mod1 = mixer.blend('aumwi.ModuleList', id = 'b099ce7e-fa35-4a1c-a418-c0be75c677f9' ) mod2 = ModuleList(
id = 'b099ce7e-fa35-4a1c-a418-c0be75c677f9',
smid = 9223372036854775800,
name = 'Soldering Iron: Hunka Hunka Burning Metal'
)
mod2.save(force_insert = True), 'Should raise IntegrityError: ModuleList.id'

def test_empty_fields(self): #Exception raised when the relational integrity of the database is affected '''
I am not testing Module.id here. This test does not work for the id,
I think because the system is designed to assign one at the time of saving.
'''
with self.assertRaises(IntegrityError):
# roll back transaction to a clean state before letting the IntegrityError bubble up

with transaction.atomic():
# This code executes inside a transaction.

obj = mixer.blend('aumwi.ModuleList', smid = None ), 'Should raise IntegrityError: ModuleList.smid' with self.assertRaises(IntegrityError):
with transaction.atomic():
obj = mixer.blend('aumwi.ModuleList', name = None ), 'Should raise IntegrityError: ModuleList.name'

class TestAuthUser(TestCase): # Must explicitly be given inputs
def test_init(self):
obj = mixer.blend('aumwi.AuthUser',
user_id = 'f92f4747-7cd4-4afd-990b-8d0185370038',
smid_id = 'a9147eda-ed55-4b9c-bff0-192a6d580a6b')
a_user = AuthUser.objects.all()
self.assertEqual(len(a_user), 1), 'Should create an AuthUser instance.'

class TestUsageLog(TestCase): # Must explicitly be given inputs
def test_init(self):
obj = mixer.blend('aumwi.UsageLog',
user_id = '5dad0428-1da1-4d6d-8cd2-ca88ad23a6f6', smid_id = '087e4535-15dd-4381-a2f5-a2ba938ff880',
)
u_log = UsageLog.objects.all()
self.assertEqual(len(u_log), 1), 'Should create a UsageLog instance.'

About the code:

I’ve tried to comment the code to explain why certain things are used and what results should be for tests, but feel a bit more clarification might be helpful.

mixer:

As stated earlier in this document, mixer is a test fixture creator.

You could use standard object implementation… Or use mixer and save many lines of coding obj = User(
id = '5dad0428-1da1-4d6d-8cd2-ca88ad23a6f6',
username = 'tinyrobotarmy',
full_name = 'Yo Momma binShoppin', short_name = 'Yo Mom',
email = 'dontpantsme@gmail.com', rfid = 9223372036854775807,
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

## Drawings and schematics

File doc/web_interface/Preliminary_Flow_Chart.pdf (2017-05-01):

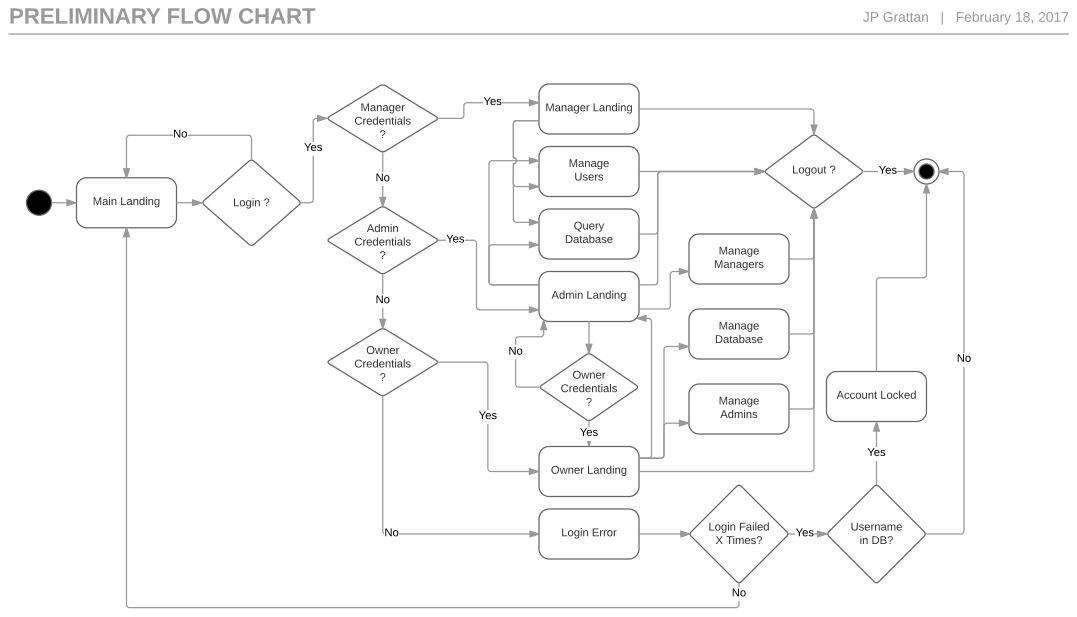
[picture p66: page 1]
PRELIMINARY FLOW CHART; JP Grattan; February 18, 2017; Main Landing; Manager Landing; Login ?; Admin Landing; Login Error; Manage Database; Manage Users; Query; Database; Manage Managers; Login Failed X Times?; Account Locked; Owner Landing; Manage Admins; Logout ?; Yes; Username; Manager Credentials; Admin Credentials; Owner Credentials

in DB? Yes

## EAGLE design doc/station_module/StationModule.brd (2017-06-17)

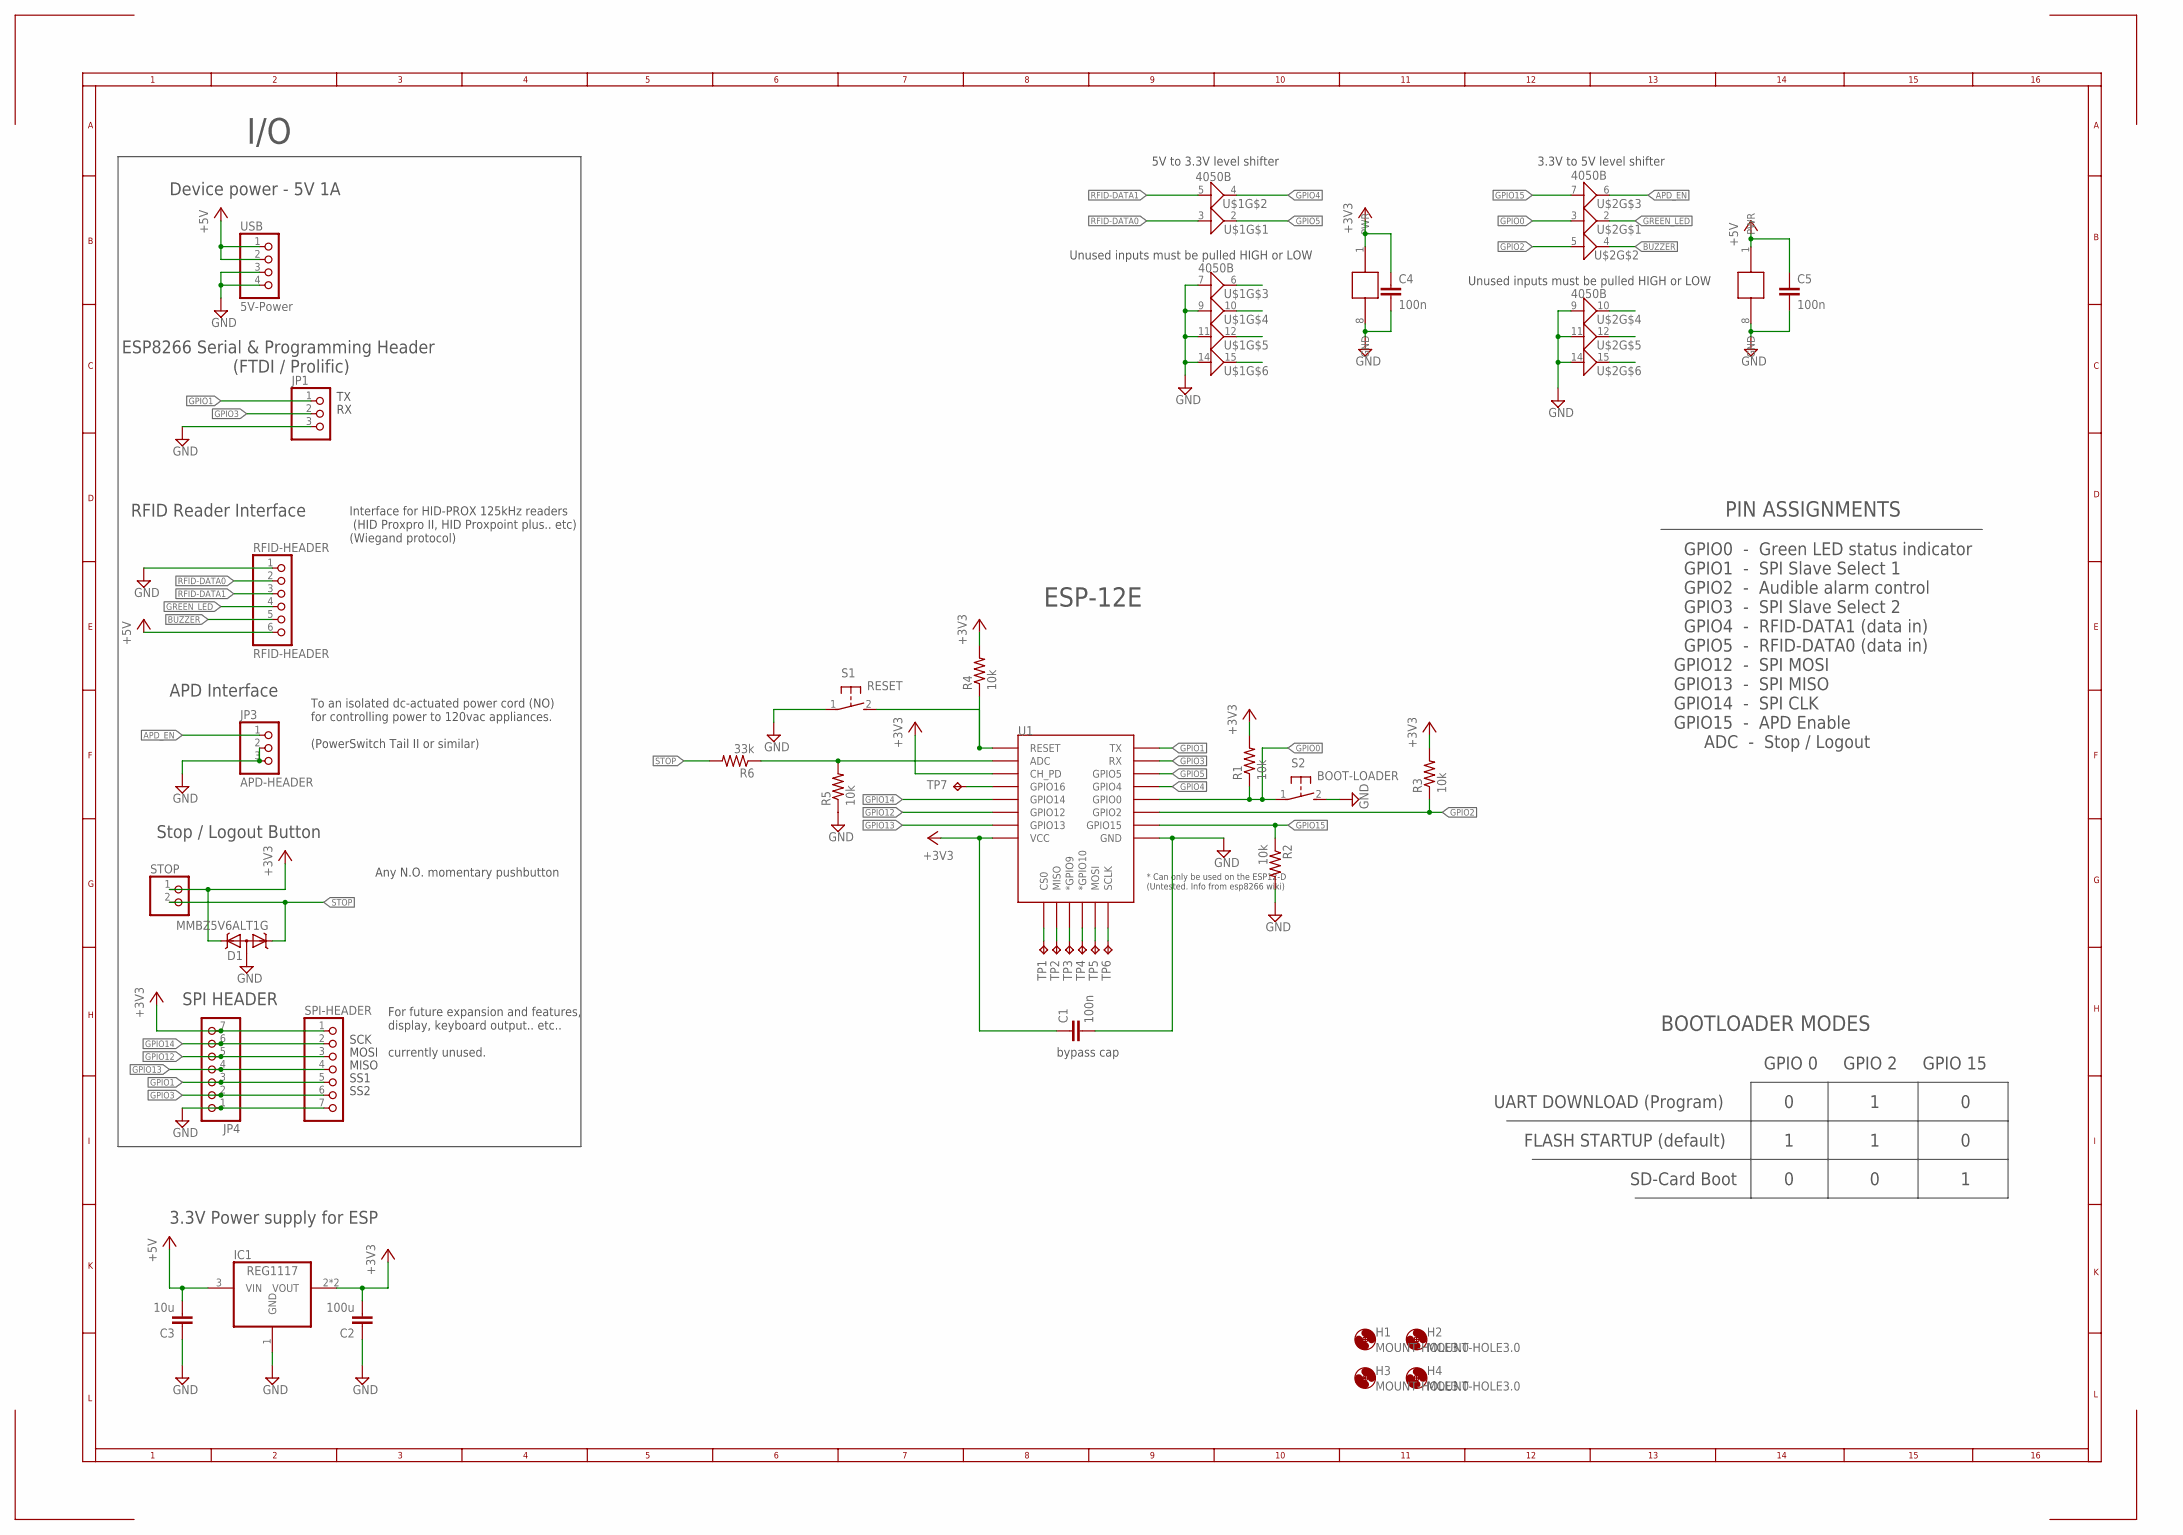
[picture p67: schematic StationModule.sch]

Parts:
C1, C4, C5: 100n; C0805K
C2: 100u; C0805K
C3: 10u; C0805K
D1: MMBZ5V6ALT1G; SOT23
H1, H2, H3, H4: MOUNT-HOLE3.0; 3,0
IC1: REG1117; SOT223
JP1: PINHD-1X3; 1X03
JP3: APD-HEADER; 1X03
JP4: PINHD-1X7; 1X07
R1, R2, R3, R4, R5: 10k; R0805
R6: 33k; R0805
RFID-HEADER: RFID-HEADER; 1X06
S1: RESET; DTSM-3
S2: BOOT-LOADER; DTSM-3
SPI-HEADER: PINHD-1X7; 1X07
STOP: PINHD-1X2; 1X02
TP1, TP2, TP3, TP4, TP5, TP6, TP7: TPB1,27; B1,27
U1: ESP12ESMD; ESP12E-SMD
U$1, U$2: 4050B; SOIC16N
USB: 5V-Power; 1X04

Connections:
+3V3: C1.1, C2.2, C4.1, D1.2 (K2), IC1.2 (VOUT), IC1.4 (VOUT), JP4.7, R1.2, R3.2, R4.2, SPI-HEADER.1, STOP.1, U1.CH_PD, U1.VCC, U$1.1 (PWR)
+5V: C3.2, C5.1, IC1.3 (VIN), RFID-HEADER.6, U$2.1 (PWR), USB.1, USB.2
ADC: R5.2, R6.1, U1.ADC
APD_EN: JP3.1, U$2.6
BUZZER: RFID-HEADER.5, U$2.4
GND: C1.2, C2.1, C3.1, C4.2, C5.2, D1.3 (AA), IC1.1 (GND), JP1.3, JP3.2, JP3.3, JP4.1, R2.2, R5.1, RFID-HEADER.1, S1.1, S2.2, SPI-HEADER.7, U1.GND, U$1.7, U$1.8 (GND), U$1.9, U$1.11, U$1.14, U$2.8 (GND), U$2.9, U$2.11, U$2.14, USB.3, USB.4
GPIO0: R1.1, S2.1, U1.GPIO0, U$2.3
GPIO1: JP1.1, JP4.3, SPI-HEADER.5, U1.TXD0 (TX)
GPIO2: R3.1, U1.GPIO2, U$2.5
GPIO3: JP1.2, JP4.2, SPI-HEADER.6, U1.RXD0 (RX)
GPIO4: U1.GPIO4, U$1.4
GPIO5: U1.GPIO5, U$1.2
GPIO12: JP4.5, SPI-HEADER.3, U1.GPIO12
GPIO13: JP4.4, SPI-HEADER.4, U1.GPIO13
GPIO14: JP4.6, SPI-HEADER.2, U1.GPIO14
GPIO15: R2.1, U1.GPIO15, U$2.7
GREEN_LED: RFID-HEADER.4, U$2.2
unnamed: TP7.TP, U1.GPIO16
unnamed: TP1.TP, U1.CS0
unnamed: TP2.TP, U1.MISO
unnamed: TP3.TP, U1.GPIO9 (*GPIO9)
unnamed: TP4.TP, U1.GPIO10 (*GPIO10)
unnamed: TP5.TP, U1.MOSI
unnamed: TP6.TP, U1.SCLK
RESET: R4.1, S1.2, U1.RESET
RFID-DATA0: RFID-HEADER.2, U$1.3
RFID-DATA1: RFID-HEADER.3, U$1.5
STOP: D1.1 (K1), R6.2, STOP.2

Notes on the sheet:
bypass cap
Device power - 5V 1A
I/O
ESP8266 Serial & Programming Header (FTDI / Prolific)
RFID Reader Interface
3.3V Power supply for ESP
ESP-12E
APD Interface
Unused inputs must be pulled HIGH or LOW
5V to 3.3V level shifter
3.3V to 5V level shifter
SPI HEADER
SS1
SS2
SCK
MOSI
MISO
Stop / Logout Button
BOOTLOADER MODES
GPIO 0 GPIO 2 GPIO 15 0 1 0 1 1 0 0 0 1
UART DOWNLOAD (Program) FLASH STARTUP (default) SD-Card Boot
GPIO0 - Green LED status indicator GPIO1 - SPI Slave Select 1 GPIO2 - Audible alarm control GPIO3 - SPI Slave Select 2 GPIO4 - RFID-DATA1 (data in) GPIO5 - RFID-DATA0 (data in) GPIO12 - SPI MOSI GPIO13 - SPI MISO GPIO14 - SPI CLK GPIO15 - APD Enable ADC - Stop / Logout
PIN ASSIGNMENTS
Interface for HID-PROX 125kHz readers (HID Proxpro II, HID Proxpoint plus.. etc) (Wiegand protocol)
Any N.O. momentary pushbutton
For future expansion and features, display, keyboard output.. etc.. currently unused.
To an isolated dc-actuated power cord (NO) for controlling power to 120vac appliances. (PowerSwitch Tail II or similar)

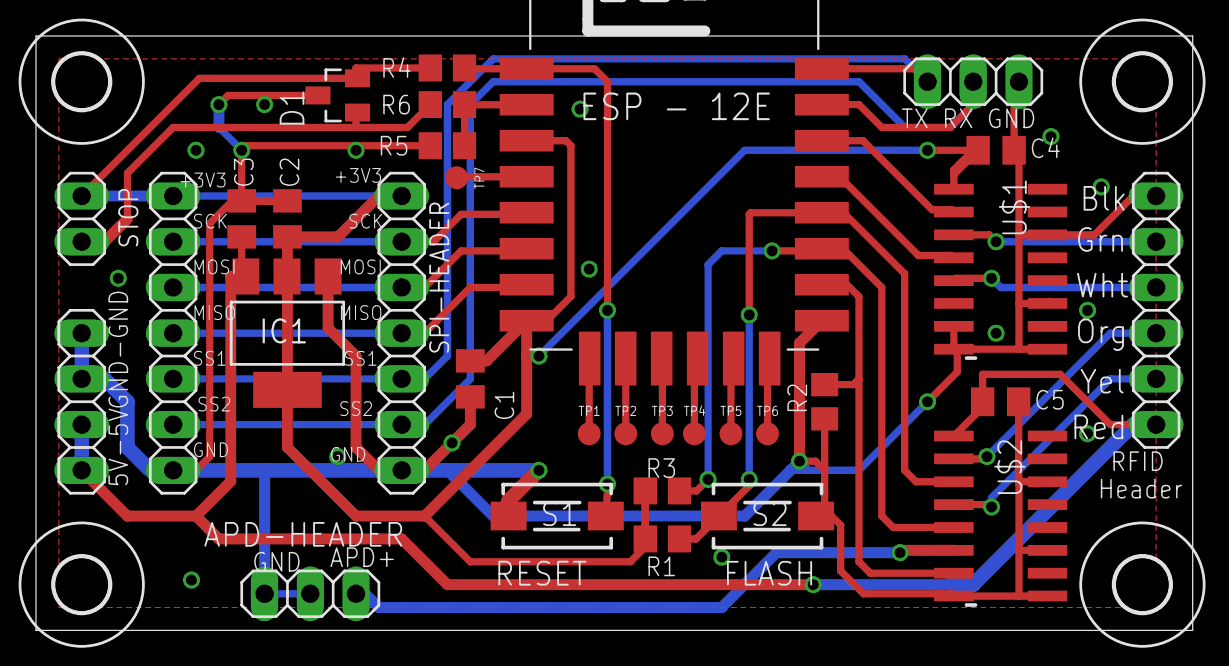
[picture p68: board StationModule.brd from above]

Board: 2 copper layers, 64.3 x 33.0 mm, 36 parts (0 on the bottom side), 28 nets.

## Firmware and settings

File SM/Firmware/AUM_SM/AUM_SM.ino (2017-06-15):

#include <ESP8266WiFi.h>          //ESP8266 Core WiFi Library
#include <EEPROM.h>
#include <DNSServer.h>            //Local DNS Server used for redirecting all requests to the configuration portal
#include <ESP8266WebServer.h>     //Local WebServer used to serve the configuration portal
#include <WiFiManager.h>          //https://github.com/tzapu/WiFiManager WiFi Configuration Magic
#include <string.h>

//IO stuff
const byte data0 = 5;  //RFID DATA0 on this pin (wiegand protocol)
const byte data1 = 4;  //RFID DATA1 on this one
const byte APD = 15; // power switch pin
const byte LEDg = 0; //green LED
const byte BEEP = 2;  //Audible alarm
//const byte SS1 = 1;  //unused
//const byte SS2 = 3;
//const byte MOSI = 12;
//const byte MISO = 13;
//const byte SPICLK = 14;

int ADCthreshold = 300;   //ADC used as digitial IO, set threshold here 0-1024

//interrupt things
byte interruptCounter = 0;
int numberOfInterrupts = 0;
char wiegand[50];
unsigned long lastInterrupt =0;
//int wiegand2RFID(); 






 String SMID = "2dd2bde1-750c-46fe-af68-5796a2bfbd0e"; // hardcoded for now
//const char* host = "aummanage.com";  //hardcoded for now
 String host = "aummanage.com";  //hardcoded for now//try this
 String path = "/aum";  //hardcoded for now

 
 char SMIDc[40];
 char hostc[40];
 char pathc[40];





void setup() {
  Serial.begin(115200);
  
    
 //EEPROM.begin(512);
//  delay(10);
//read_settings();
setupstring2char();

  String s = WiFi.macAddress();
  Serial.println("");
  Serial.println("MAC ADDRESS: ");
  Serial.println(s);

  
  delay(1000);
  setupWIFI();
 


  //setup IO
  pinMode(APD, OUTPUT);
  digitalWrite(APD, LOW); //active high
  pinMode(BEEP, OUTPUT);
  digitalWrite(BEEP, HIGH);  //active low
  pinMode(LEDg, OUTPUT);
  digitalWrite(LEDg, HIGH); //active low

Serial.println("compare settings:");

//compare_settings();

 setupinterrupt();
}





void loop(){
  
  static bool auth = 0;
  static int RFID = 0;
  static int manid = 0;
  
      if((interruptCounter > 5)   && (millis() - lastInterrupt > 25)){

        if (analogRead(A0) > ADCthreshold) {  
          Serial.println("Add user requested!");       
          manid = wiegand2RFID();
          adduser(manid);
          
          }
        else { RFID = wiegand2RFID();
         auth = postRFID(RFID);

        }
        
        
        
        Serial.print("AUTH = ");
        Serial.println(auth);
        interruptCounter = 0;
        if (auth == 1){
          Serial.println("APD enabled");
        }
        else beepslow(1);
        }


      if   ((analogRead(A0) > ADCthreshold) && (auth == 1)){
        auth = 0;
        digitalWrite(APD,LOW); //don't wait for confermation to turn off 
        beepfast(1);
        Serial.println("Logout");
        beepfast(2);
        logout();

        digitalWrite(LEDg, HIGH); //turn off green light
        digitalWrite(BEEP, HIGH); 
        
      } 
      else;


      if (auth == 1){      
        digitalWrite(APD,HIGH);
        digitalWrite(LEDg, LOW);//active low  
      }
      
      else { 
        digitalWrite(APD,LOW);
        digitalWrite(LEDg, HIGH);
       }
}

void beepfast(int beepy){
        for (int i = 0; i < beepy; i++){
        digitalWrite(BEEP, LOW); //turn on
        delay(100);
        digitalWrite(BEEP, HIGH); //turn off now
        delay(100);
        }
        
}

void beepslow(int beepy){
        for (int i = 0; i < beepy; i++){
        digitalWrite(BEEP, LOW); //turn off now
        delay(500);
        digitalWrite(BEEP, HIGH); //turn off now
        delay(500);
        }
 
}

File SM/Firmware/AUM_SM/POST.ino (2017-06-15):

#include <ESP8266HTTPClient.h>
#include <ESP8266WiFi.h>

// Use WiFiClient class to create TCP connections
WiFiClient client;

bool postRFID(int RFID) {
String str = "";
String RFIDs = String(RFID); //convert RFID to string to pass to client
String hosts = String(host);
bool auth = 0;

  Serial.print("connecting to ");
  Serial.println(host);

  if (client.connect(hostc, 80)) {
    Serial.println("Connection Established with" + hosts);
  }else {
    Serial.println("connection failed");
    return 0;
  }


String PostData = "SMID=" + SMID + "&RFID=" + RFIDs;

//String PostData = "SMID=2dd2bde1-750c-46fe-af68-5796a2bfbd0e&RFID=174470";

client.println("POST " + path + "/sm_login" + " HTTP/1.1");
client.println("Host: "+ hosts);
client.println("Cache-Control: no-cache");
client.println("Content-Type: application/x-www-form-urlencoded");
client.print("Content-Length: ");
client.println(PostData.length());
client.println();
client.println(PostData);
long interval = 2000;
unsigned long currentMillis = millis(), previousMillis = millis();

while(!client.available()){

  if( (currentMillis - previousMillis) > interval ){

    Serial.println("Timeout");
    client.stop();     
    return 0;
  }
  currentMillis = millis();
}

int id1 = 0;
while (client.connected()){
  
  if ( client.available() ){
    str=client.readStringUntil('\n');
    Serial.print(id1);
    Serial.print(" ");
    id1++;
    Serial.print(str);}
      
      
      if (str == "False"){
        Serial.println("Gota false");
       break;}
       else if (str == "True"){
        Serial.println("Gota true!");
        break;}
        else;
        
}   

   
  if (client.connected()) { 
    client.stop();  // DISCONNECT FROM THE SERVER
  }
  Serial.println();
  Serial.println("closing connectionnnnn");
  client.stop();

Serial.print("SERVER RETURNED: ");
Serial.println(str);
if (str == "True"){
  auth = 1;}
else {
  auth = 0;}




  
return (auth);
}



bool sm_add(int manid,int user) {
String str = "";
String mgr = String(manid);
String RFIDs = String(user);//convert RFID to string to pass to client
String hosts = String(host);
bool auth = 0;

  Serial.print("connecting to ");
  Serial.println(host);

  if (client.connect(hostc, 80)) {
    Serial.println("Connection Established with" + hosts);
  }else {
    Serial.println("connection failed");
    return 0;
  }


String PostData = "smid=" + SMID + "&mgr=" + mgr + "&user=" + RFIDs;
Serial.print("Post data is: ");
Serial.println(PostData);
//String PostData = "SMID=2dd2bde1-750c-46fe-af68-5796a2bfbd0e&RFID=174470";

client.println("POST " + path + "/sm_add/" + " HTTP/1.1");
client.println("Host: "+ hosts);
client.println("Cache-Control: no-cache");
client.println("Content-Type: application/x-www-form-urlencoded");
client.print("Content-Length: ");
client.println(PostData.length());
client.println();
client.println(PostData);
long interval = 2000;
unsigned long currentMillis = millis(), previousMillis = millis();

while(!client.available()){

  if( (currentMillis - previousMillis) > interval ){

    Serial.println("Timeout");
    client.stop();     
    return 0;
  }
  currentMillis = millis();
}

int id1 = 0;
while (client.connected()){
  
  if ( client.available() ){
    str=client.readStringUntil('\n');
    Serial.print(id1);
    Serial.print(" ");
    id1++;
    Serial.print(str);}
      
      
      if (str == "False"){
        Serial.println("Gota false");
       break;}
       else if (str == "True"){
        Serial.println("Gota true!");
        break;}
        else;
        
}   

   
  if (client.connected()) { 
    client.stop();  // DISCONNECT FROM THE SERVER
  }
  Serial.println();
  Serial.println("closing connectionnnnn");
  client.stop();

Serial.print("SERVER RETURNED: ");
Serial.println(str);
if (str == "True"){
  auth = 1;}
else {
  auth = 0;}

  
return (auth);
}












void logout(){
String hosts = String(host);
  Serial.print("connecting to ");
  Serial.println(host);

  if (client.connect(hostc, 80)) {
    Serial.println("Connection Established with" + hosts);
  }else {
    Serial.println("connection failed");
  }


String PostData = "SMID=" + SMID;

//String PostData = "SMID=2dd2bde1-750c-46fe-af68-5796a2bfbd0e&RFID=174470";

client.println("POST " + path +"/sm_logout" +" HTTP/1.1");
client.println("Host: "+ hosts);
client.println("Cache-Control: no-cache");
client.println("Content-Type: application/x-www-form-urlencoded");
client.print("Content-Length: ");
client.println(PostData.length());
client.println();
client.println(PostData);
long interval = 2000;
unsigned long currentMillis = millis(), previousMillis = millis();

while(!client.available()){

  if( (currentMillis - previousMillis) > interval ){

    Serial.println("Timeout");
    client.stop();     
  }
  currentMillis = millis();
}

  
 if (client.connected()) { 
    client.stop();  // DISCONNECT FROM THE SERVER
  }
  Serial.println();
  Serial.println("closing connectionnnnn");
  client.stop();

Serial.println("Logged out");
}

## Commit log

2017-02-15 Updated SM HW stuff
    [espshield.sch]
2017-02-18 File Shuffling + WI Flow Chart
    I created folders to house the documents I was creating. Included in
    this upload is the Preliminary Web Flow Chart. Web Interface State
    Diagram pending.
2017-03-10 Station module schematic
    [StationModule.sch]
2017-03-17 Add files via upload
    Use Cases: database & web framework V1.2
2017-03-24 current working stuff
    newer
2017-03-24 Rebased File System
    Moved recent changes into correct file structures and renamed web
    interface folders to correspond with maturing project.
    [StationModule.sch, espshield.sch]
2017-03-27 removed Questions and Choices, modified punches
    questions and choices have been commented out but are still there, just
    in case.
    Punches has been modified to act correctly.
2017-04-10 Updated SM
    [StationModule.sch]
2017-04-10 SM rev1
    [StationModule.brd, StationModule.sch]
2017-04-10 SM revision 1
    [StationModule.sch]
2017-04-14 Schematic annotation
    [StationModule.brd, StationModule.sch]
2017-04-14 Uploaded BOM to SM readme
2017-05-05 SM v1.1
    with fixes
    [StationModule.brd, StationModule.sch]
2017-05-05 sm board
    moist current one
    [StationModule.brd]
2017-05-05 updated sch
    labeling conventions from andrew
    [StationModule.sch]
2017-06-16 crazy rebase
    attempt to just do all 5232 changes
    [StationModule.brd, StationModule.sch, espshield.sch]
2017-06-17 JP deleted the last one
    [StationModule.brd, StationModule.sch]
2017-06-17 Issues fixed
    [StationModule.brd, StationModule.sch]
2017-06-19 Final Rebase
    Moved all documentation to the ./doc directory.
    Renamed all directories and files to be GNU compatible
    Added User Manual
    Added original html templates
    [StationModule.brd, StationModule.sch, espshield.sch]
